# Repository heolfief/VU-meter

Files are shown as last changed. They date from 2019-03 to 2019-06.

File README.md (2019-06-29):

# VU-meter

<p align="center">
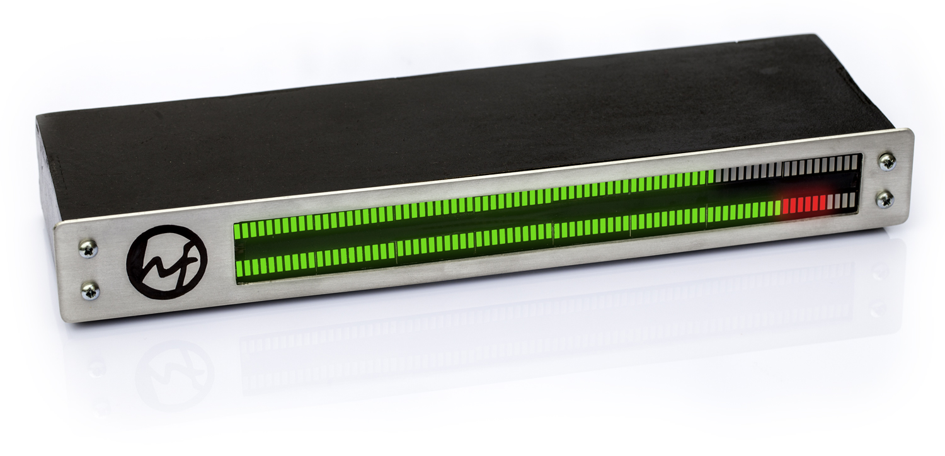
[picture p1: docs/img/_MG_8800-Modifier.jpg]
		
</p>

## Table of contents

- [Description](#description)
- [Hardware](#hardware)
- [Software](#software)
- [Copyright and license](#copyright-and-license)

## Description
This project is an AVR based LED VU-meter. It's display consists of 80 LEDs per audio channel. Each PCB holds all the LEDs, the analog and digital segments of the circuit and only handle one audio channel. That way you can build a stereo VU-meter just by using two instances of this circuit (which can be mechanically stacked together). Each audio channel will be completely separated and computed separately by the AVR microcontroller on each PCB.

### Pictures
<p align="center">
		
</p>
<p align="center">
		
</p>
<p align="center">
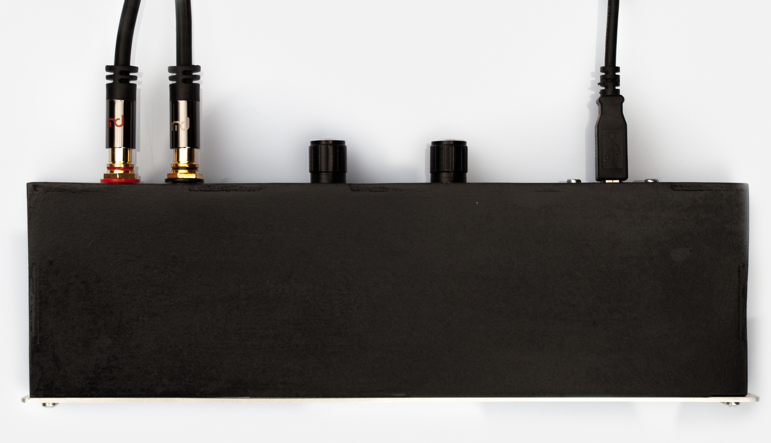
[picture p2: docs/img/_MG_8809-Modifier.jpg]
		
</p>

## Hardware
The hardware is based on 3 main components:
- ATmega328p AVR microcontroller
- MCP6004 quad op-amp
- 74HC595 shift-registers for extended MCU outputs

This board runs on 5V DC power and should not exceed 500mA of current draw (All LEDs lit up).
A stabilized power supply is needed in order to provide clean power to the analog circuit.

### PCB
Populated PCB picture:
<p align="center">
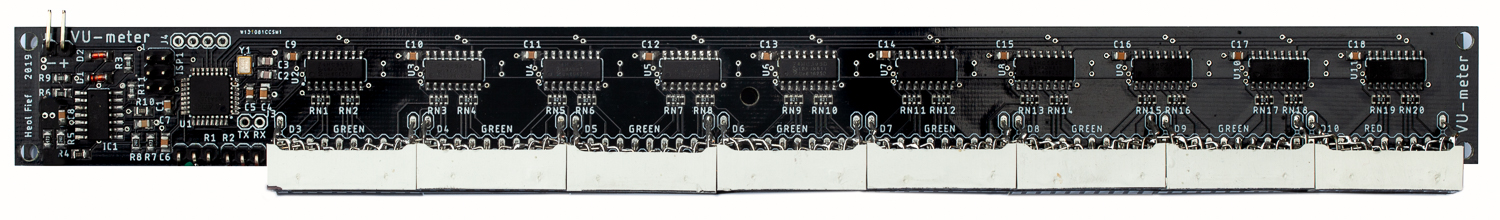
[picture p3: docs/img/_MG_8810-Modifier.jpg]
		
</p>

Bare PCB pictures:
<p align="center">
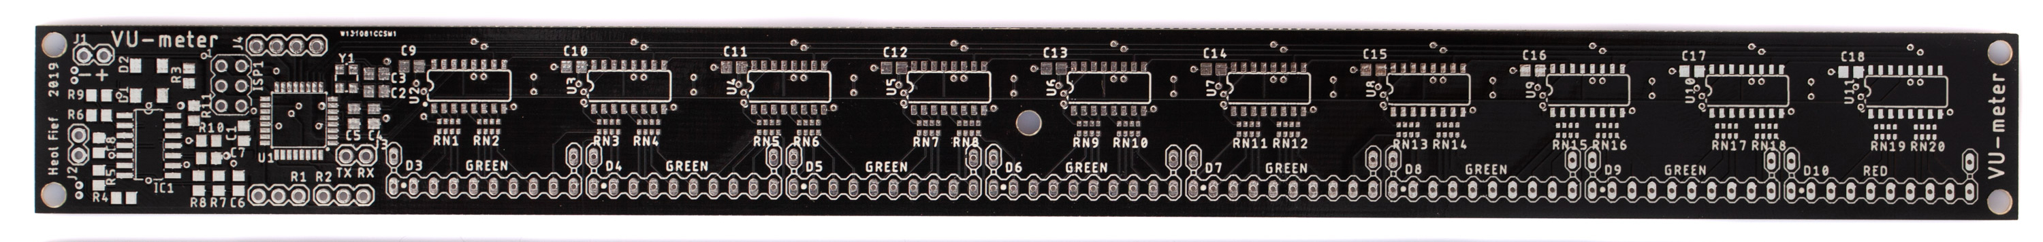
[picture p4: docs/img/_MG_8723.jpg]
		
</p>
<p align="center">
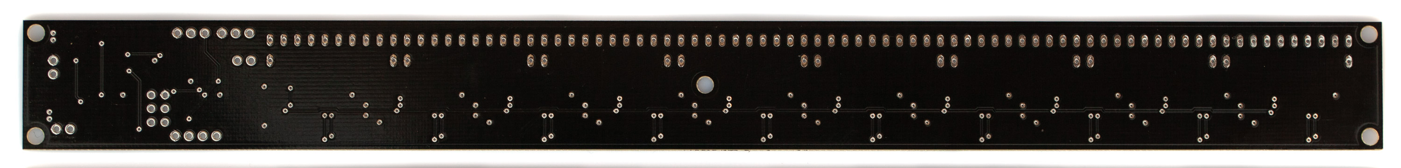
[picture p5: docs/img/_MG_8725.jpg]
		
</p>

The PCB was manufactured by <a target="_blank" href="https://www.pcbway.com">PCBWay</a>. Total cost was 44$ including shipping to France by DHL for 5 pieces.

I received the PCB 6 days after placing order on their website. General quality is good. Highly recommend their service.

<p align="center">
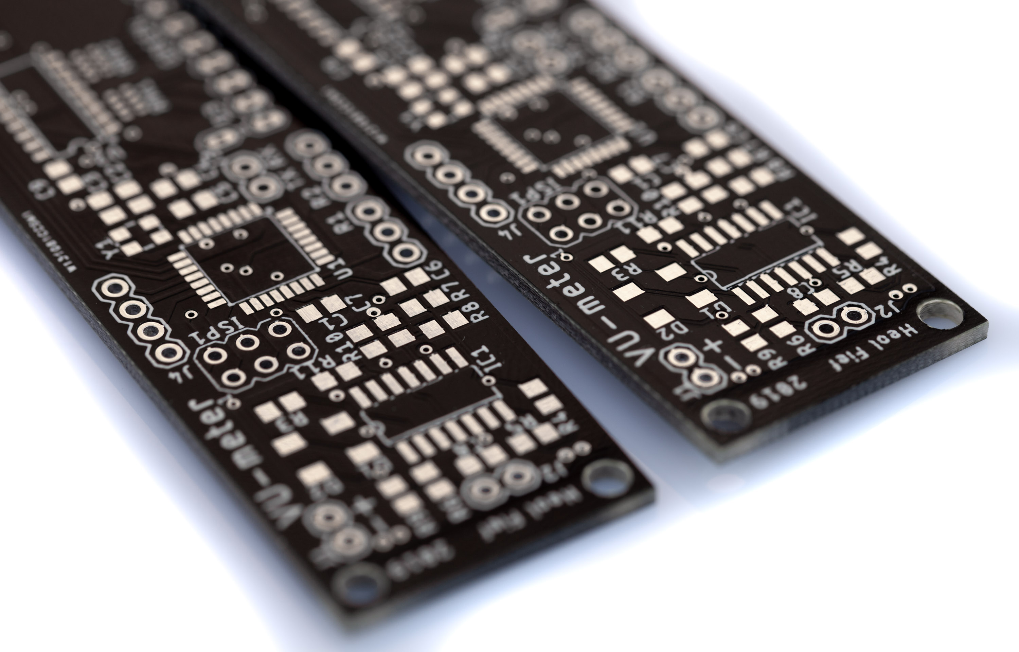
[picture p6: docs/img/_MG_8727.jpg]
		
</p>

### Documents available

- <a target="_blank" href="https://github.com/heolfief/VU-meter/blob/master/Hardware/Schematics.pdf">Schematics (PDF)</a>
- <a target="_blank" href="https://github.com/heolfief/VU-meter/blob/master/Hardware/BOM.pdf">Bill of materials (PDF)</a>
- <a target="_blank" href="https://github.com/heolfief/VU-meter/blob/master/Hardware/CAD/Eagle%20files">Autodesk Eagle CAD files</a>
- <a href="https://github.com/heolfief/VU-meter/tree/master/Hardware/CAD/GerberFiles">Gerber files</a>

## Software
The Firmware for the AVR microcontroller is written in C.

- IDE : Atmel Studio 7.0 (can be opened in MPLAB X)
- Compiler : avr-gcc

### Documents available

- <a target="_blank" href="https://heolfief.github.io/VU-meter/">Code documentation (doxygen)</a>

## Copyright and license
heolfief/VU-meter is licensed under the GNU General Public License v3.0.

See the <a target="_blank" href="https://github.com/heolfief/VU-meter/blob/master/LICENSE">LICENSE file</a> for more information.

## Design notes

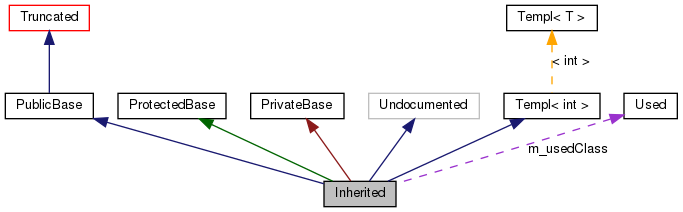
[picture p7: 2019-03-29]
docs/graph_legend.png

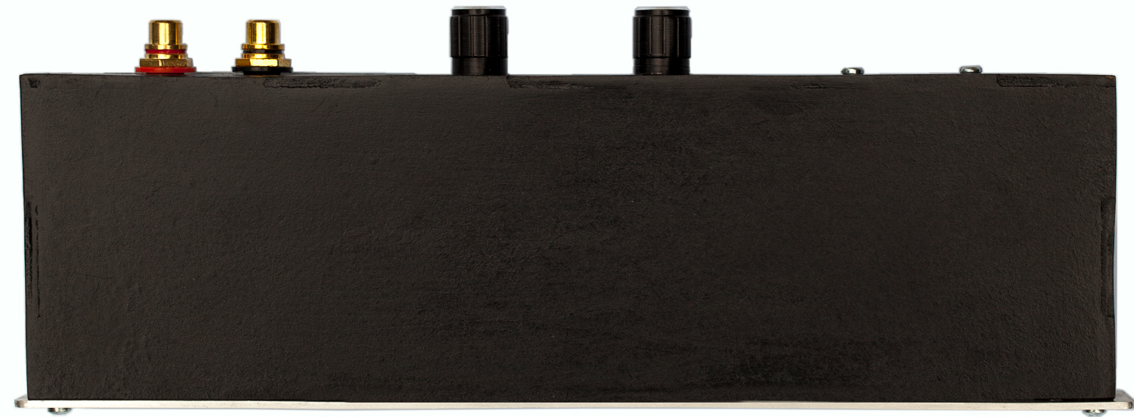
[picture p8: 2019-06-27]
docs/img/_MG_8802-Modifier.jpg

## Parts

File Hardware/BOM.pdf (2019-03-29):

BOM
Qty Value | Device | Package | Parts | Description
7 | 100k | R-EU_R0805 | R0805 | R3, R4, R5, R6, R9, R10, R11 | RESISTOR, European symbol
15 | 100n | C-EUC0805 | C0805 | C1, C4, C5, C6, C8, C9, C10, C11, C12, C13, C14, C15, C16, C17, C18 | CAPACITOR, European symbol
2 | 10k | POT_OFFBOARD | 1X03 | R1, R2 | Potentiometer with 3 pins connector for offboard wiring
1 | 16MHz | CRYSTALSMD-3.2X2.5 | CRYSTAL-SMD-3.2X2.5MM | Y1 | Crystals (Generic)
2 | 1N4148 | D-SOD-80 | SOD80 | D1, D2 | DIODE
1 | 22n | C-EUC0805 | C0805 | C7 | CAPACITOR, European symbol
2 | 22p | C-EUC0805 | C0805 | C2, C3 | CAPACITOR, European symbol
1 | 24k | R-EU_R0805 | R0805 | R8 | RESISTOR, European symbol
1 | 47k | R-EU_R0805 | R0805 | R7 | RESISTOR, European symbol
20 | 820 | 4R-N0603-ARC | 0603-ARC | | Array Chip Resistor
1 | ATMEGA328P_TQFP ATMEGA328P_TQFP | TQFP32-08 | U1 | Popular 328P in QFP
1 | AVRISP-6 | AVRISP-6 | AVRISP | ISP1 | AVR ISP HEADER
7 | GREEN | LED_BARGRAPH | LED_BARGRAPH | D3, D4, D5, D6, D7, D8, D9 | LED bargraph, right angle soldering
1 | MCP6004 | QUAD_OPAMPD | SO14 | IC1 | OP AMP
1 | PWR in (+5V) | CONN_02 | 1X02 | J1 | Generic Header 0.1 inch spaced
1 | SGNL_IN | CONN_02 | 1X02 | J2 | Generic Header 0.1 inch spaced
1 | RED | LED_BARGRAPH | LED_BARGRAPH | D10 | LED bargraph, right angle soldering
10 | SN74HC595D | 74HC595D | SO16 | U2, U3, U4, U5, U6, U7, U8, U9, U10, U11 | 8-Bit Shift Register (Serial to Parallel)

RN1, RN2, RN3, RN4, RN5, RN6, RN7, RN8, RN9, RN10, RN11, RN12, RN13, RN14, RN15, RN16, RN17, RN18, RN19, RN20

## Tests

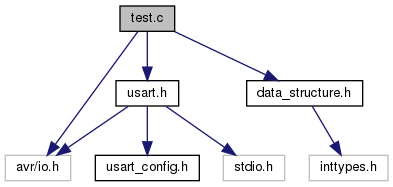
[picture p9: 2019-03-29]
docs/test_8c__incl.png

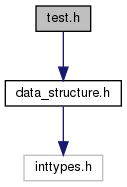
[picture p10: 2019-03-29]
docs/test_8h__incl.png

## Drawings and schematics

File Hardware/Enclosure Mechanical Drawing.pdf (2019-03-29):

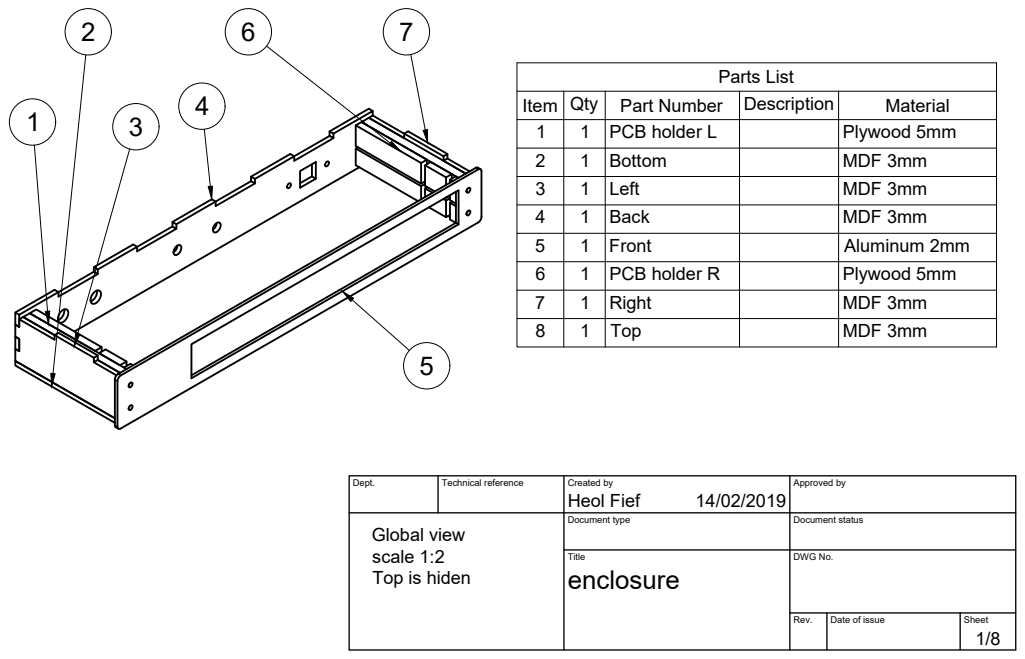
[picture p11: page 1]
Parts List

Item | Qty | Part Number | Description | Material
1 | 1 | PCB holder L | | Plywood 5mm
2 | 1 | Bottom | | MDF 3mm
3 | 1 | Left | | MDF 3mm
4 | 1 | Back | | MDF 3mm
5 | 1 | Front | | Aluminum 2mm
6 | 1 | PCB holder R | | Plywood 5mm
7 | 1 | Right | | MDF 3mm
8 | 1 | Top | | MDF 3mm

Dept. | Technical reference | Created by Heol Fief 14/02/2019 | Approved by

Global view scale 1:2 Top is hiden | | Document type | Document status

Title enclosure | DWG No.

Rev. | Date of issue | Sheet

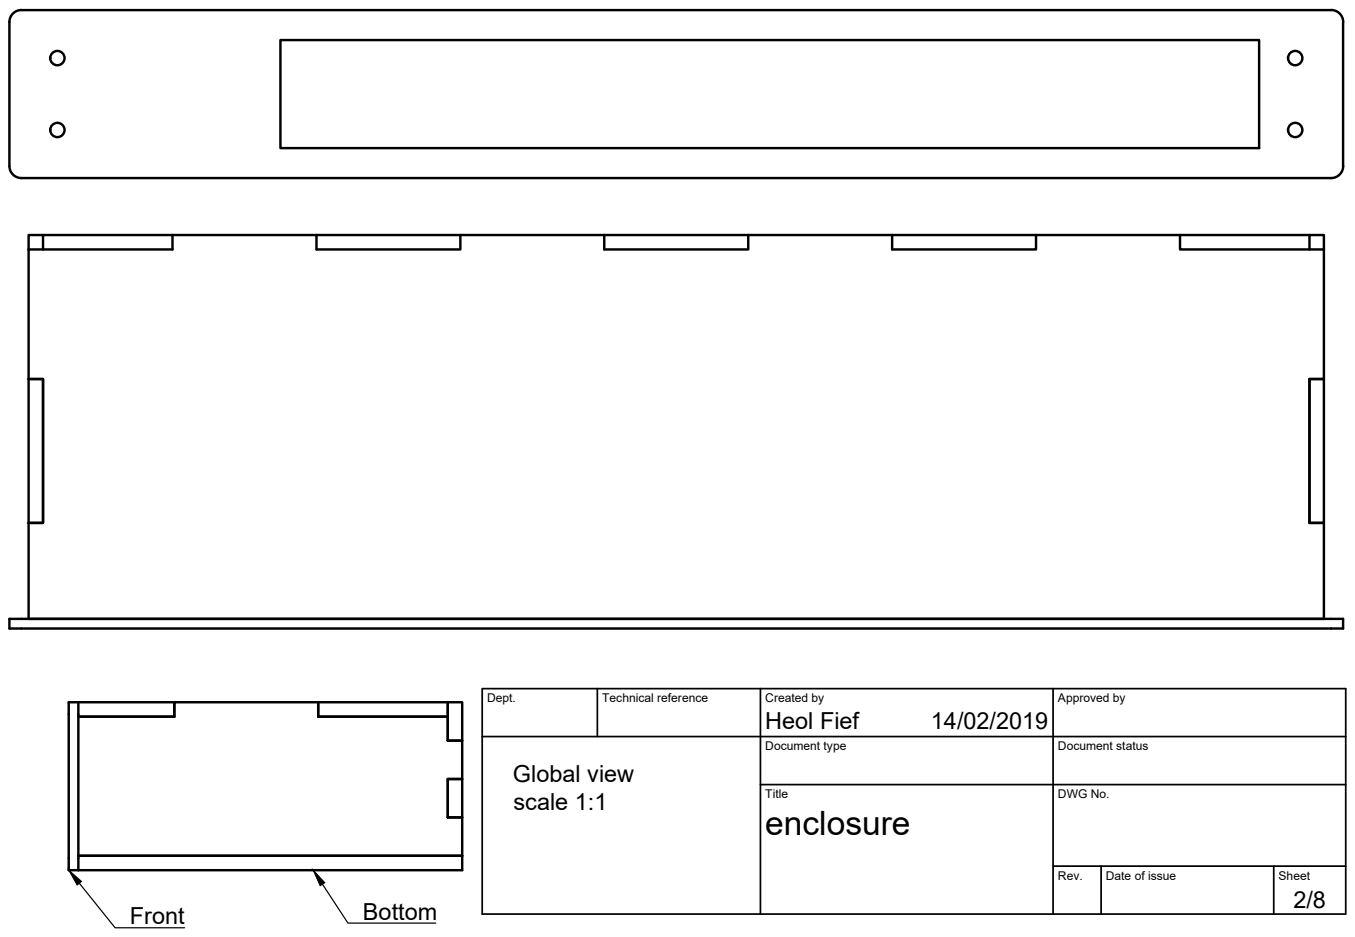
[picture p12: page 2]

Dept. | Technical reference | Created by Heol Fief 14/02/2019 | Approved by

Global view scale 1:1 | | Document type | Document status

Title enclosure | DWG No.

Rev. | Date of issue | Sheet

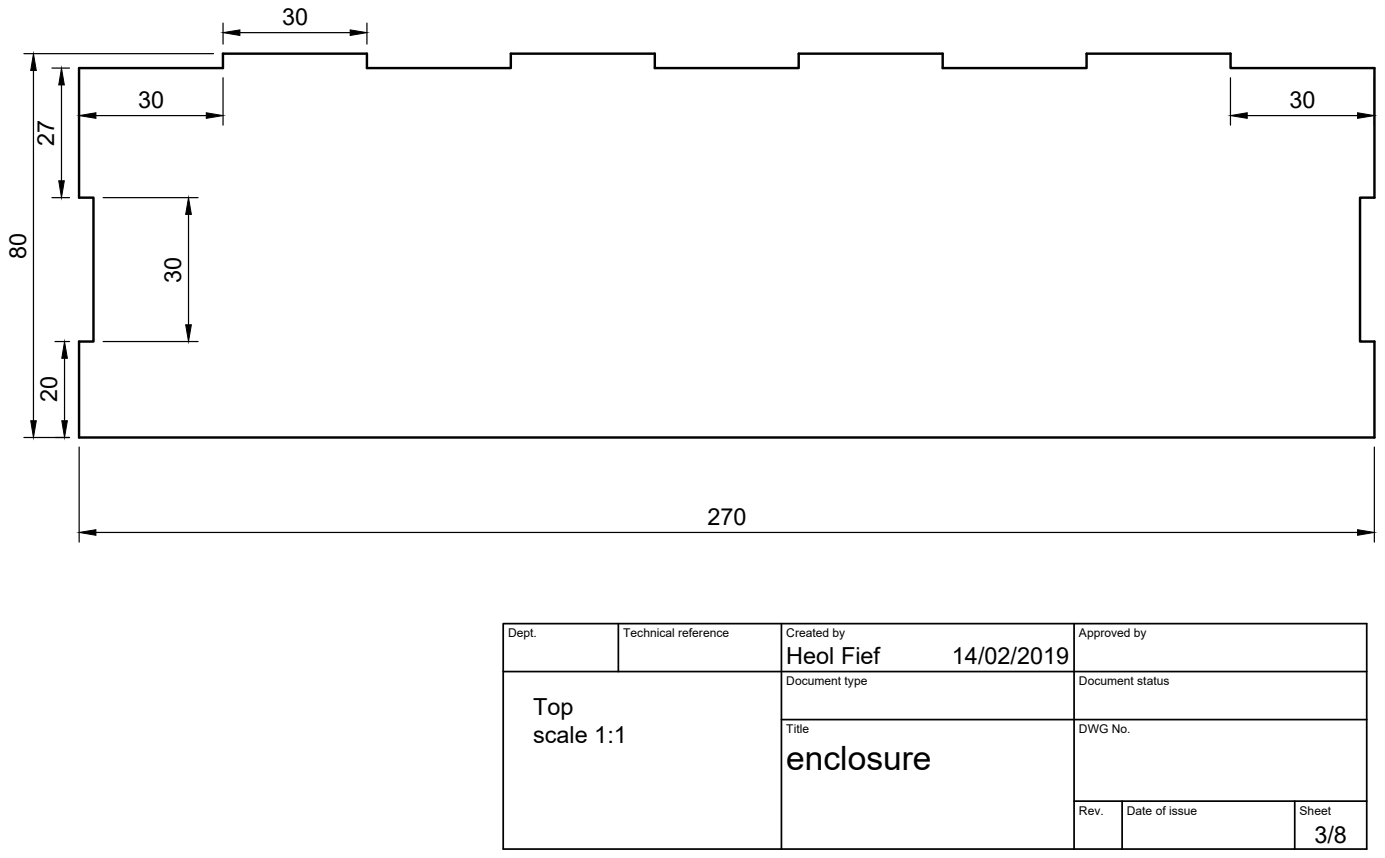
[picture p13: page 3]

Dept. | Technical reference | Created by Heol Fief 14/02/2019 | Approved by

Top scale 1:1 | | Document type | Document status

Title enclosure | DWG No.

Rev. | Date of issue | Sheet

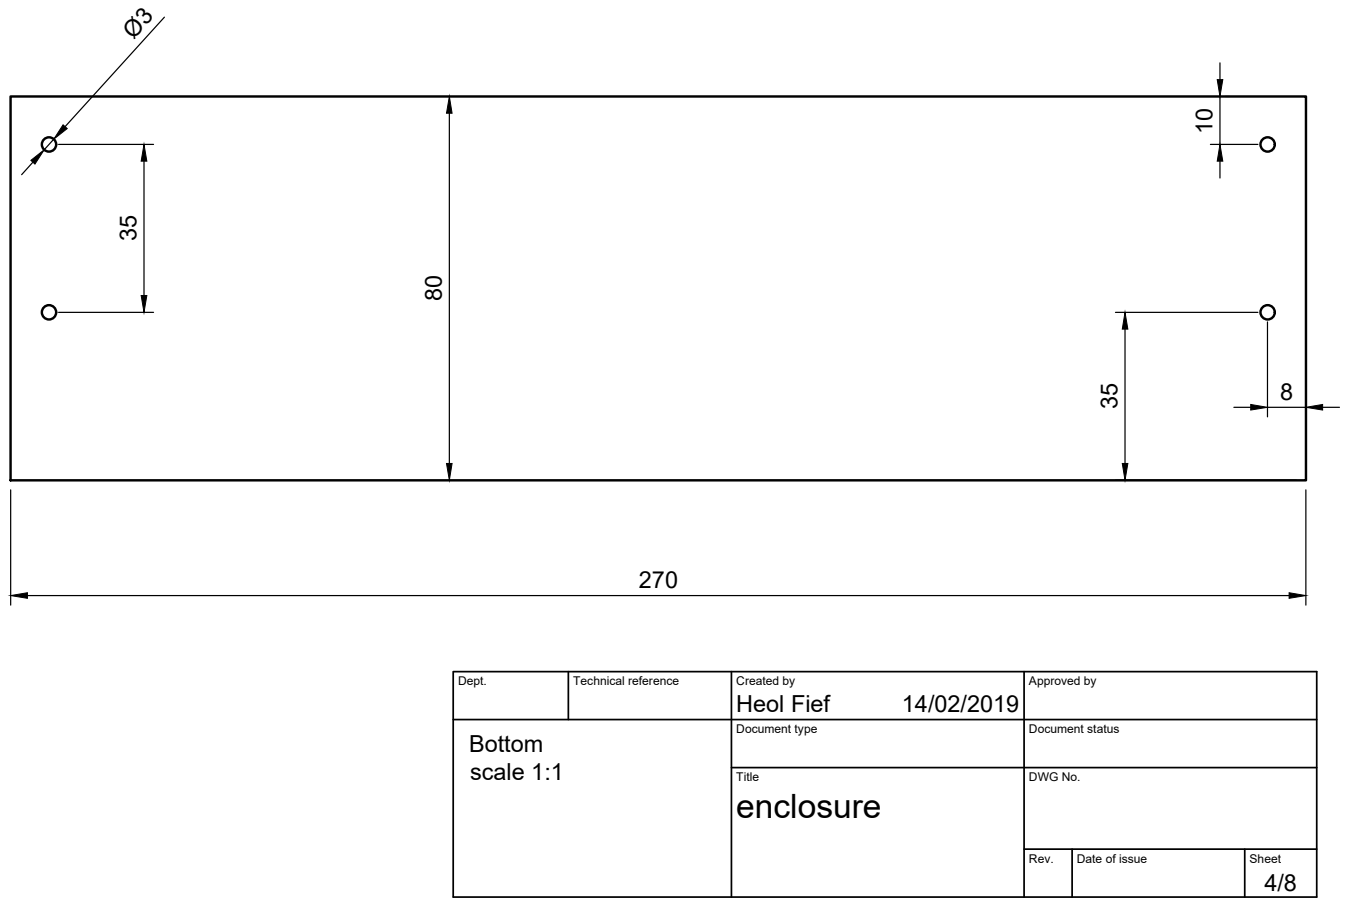
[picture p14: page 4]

Dept. | Technical reference | Created by Heol Fief 14/02/2019 | Approved by

Bottom scale 1:1 | | Document type | Document status

Title enclosure | DWG No.

Rev. | Date of issue | Sheet

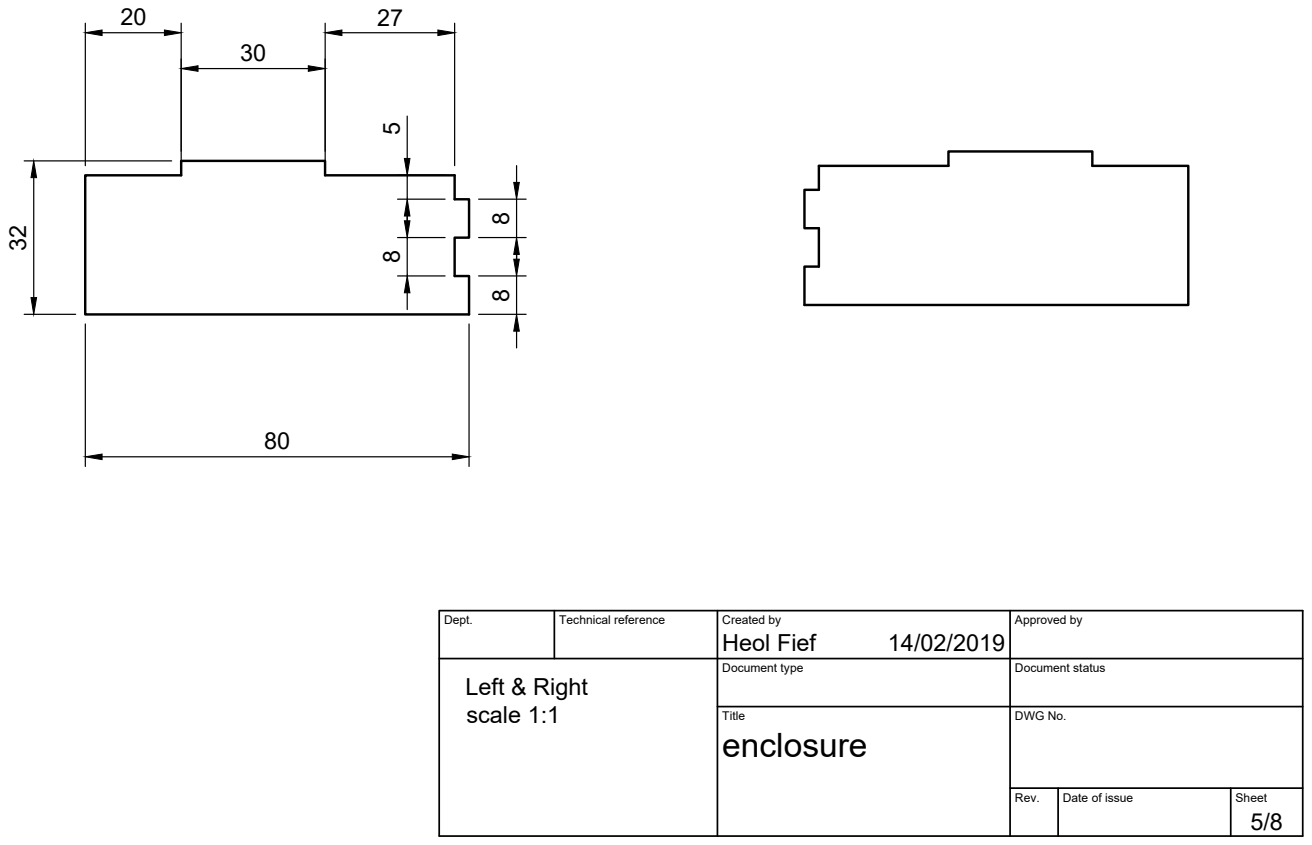
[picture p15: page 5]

Dept. | Technical reference | Created by Heol Fief 14/02/2019 | Approved by

Left & Right scale 1:1 | | Document type | Document status

Title enclosure | DWG No.

Rev. | Date of issue | Sheet

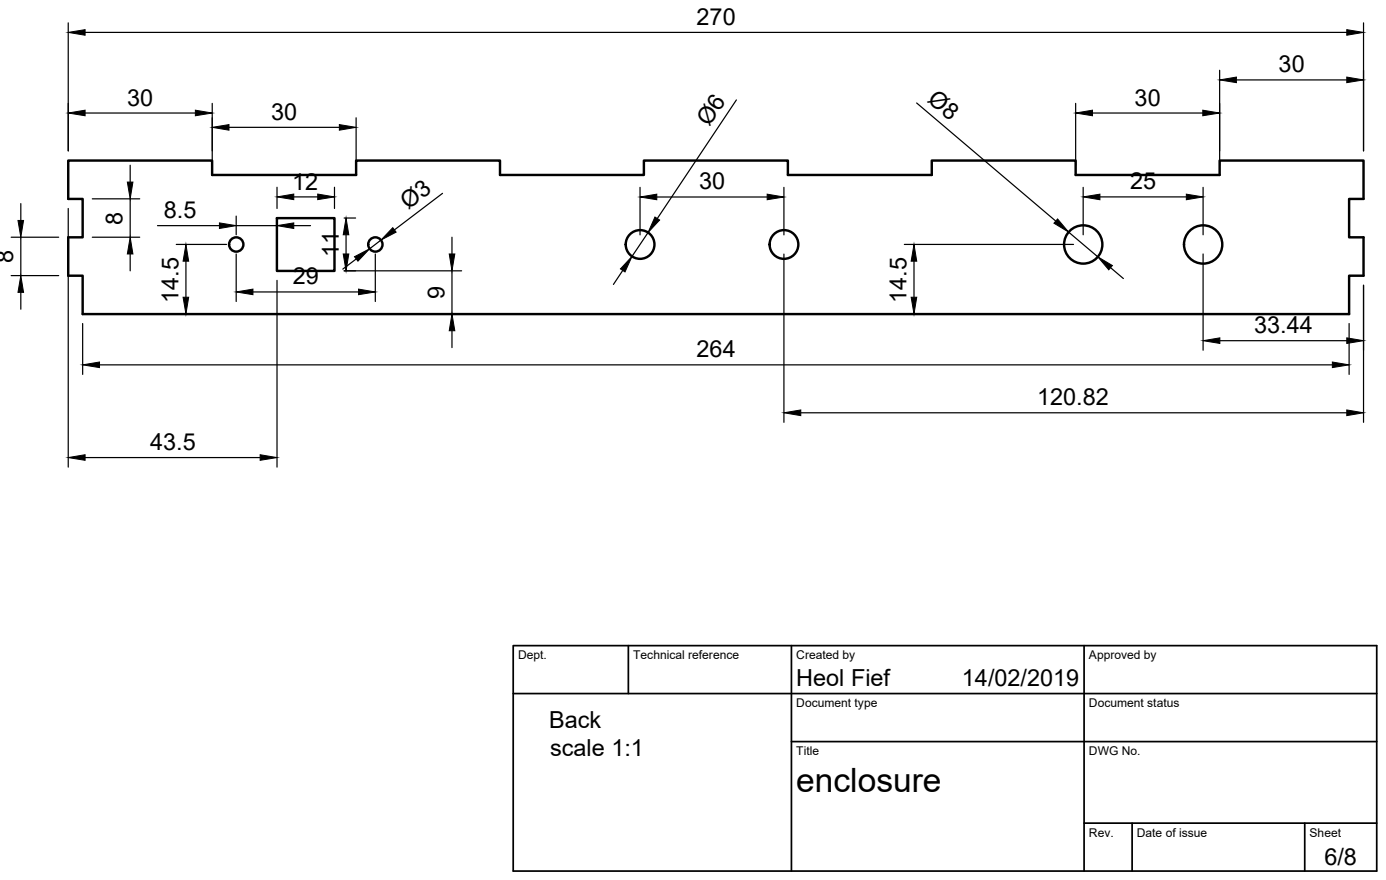
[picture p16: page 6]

Dept. | Technical reference | Created by Heol Fief 14/02/2019 | Approved by

Back scale 1:1 | | Document type | Document status

Title enclosure | DWG No.

Rev. | Date of issue | Sheet

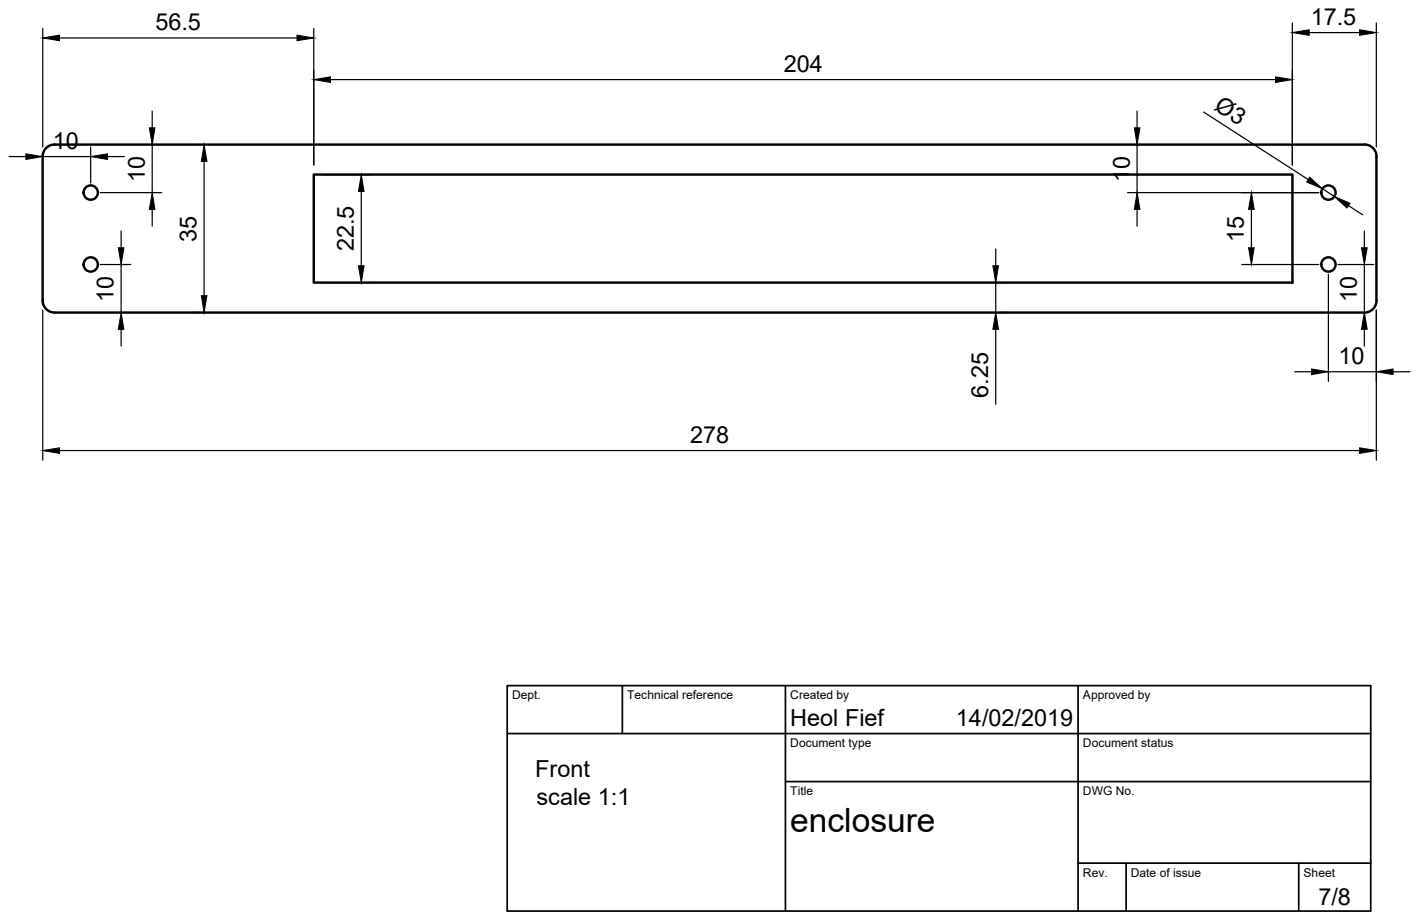
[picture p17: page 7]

Dept. | Technical reference | Created by Heol Fief 14/02/2019 | Approved by

Front scale 1:1 | | Document type | Document status

Title enclosure | DWG No.

Rev. | Date of issue | Sheet

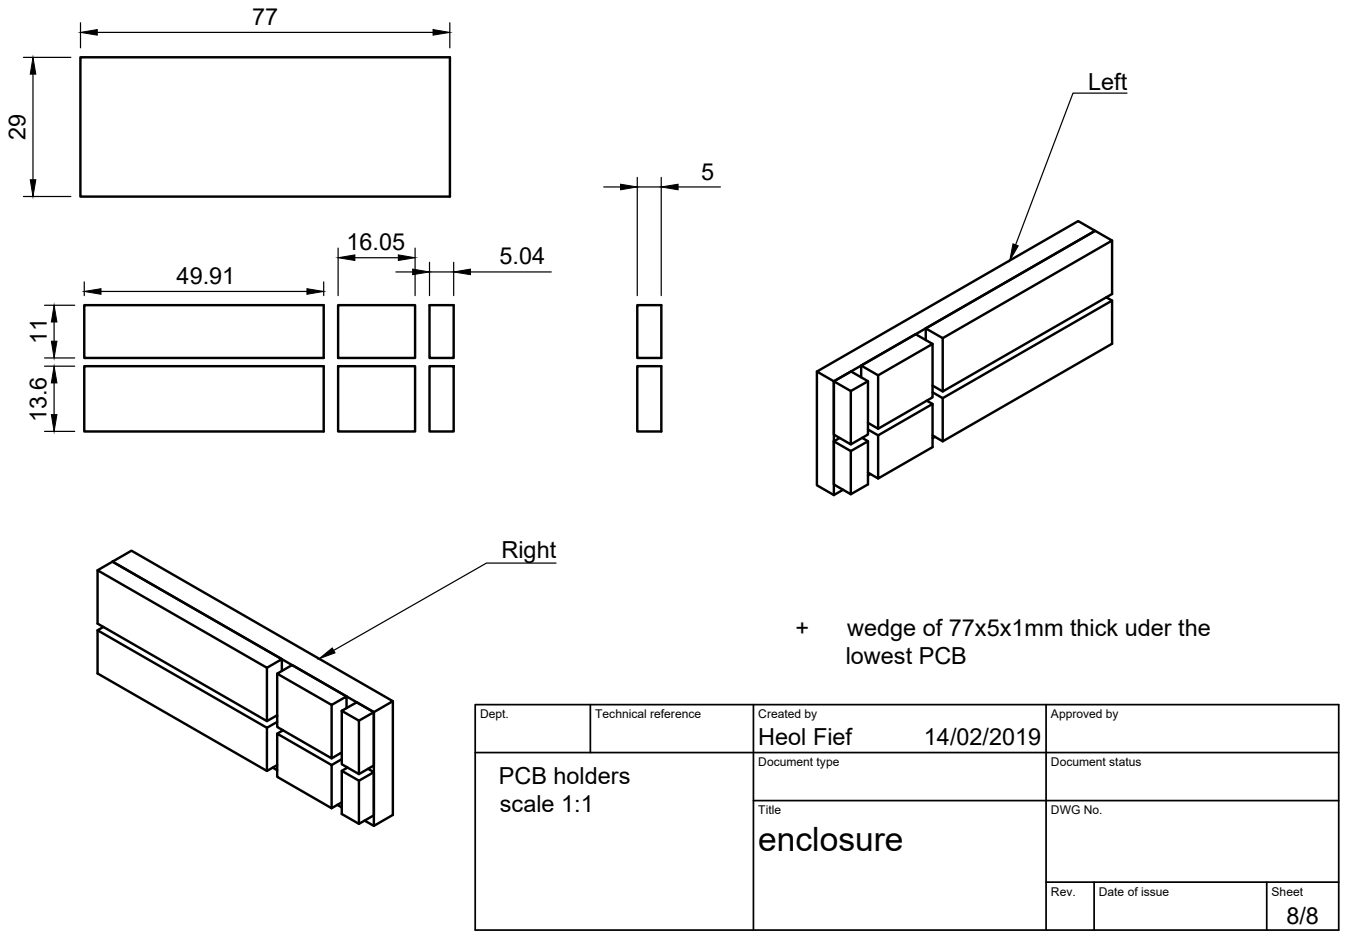
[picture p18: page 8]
Heol Fief 29; wedge of 77x5x1mm thick uder the; lowest PCB

Dept. | Technical reference | Created by 14/02/2019 | Approved by

PCB holders scale 1:1 | | Document type | Document status

Title enclosure | DWG No.

Rev. | Date of issue | Sheet

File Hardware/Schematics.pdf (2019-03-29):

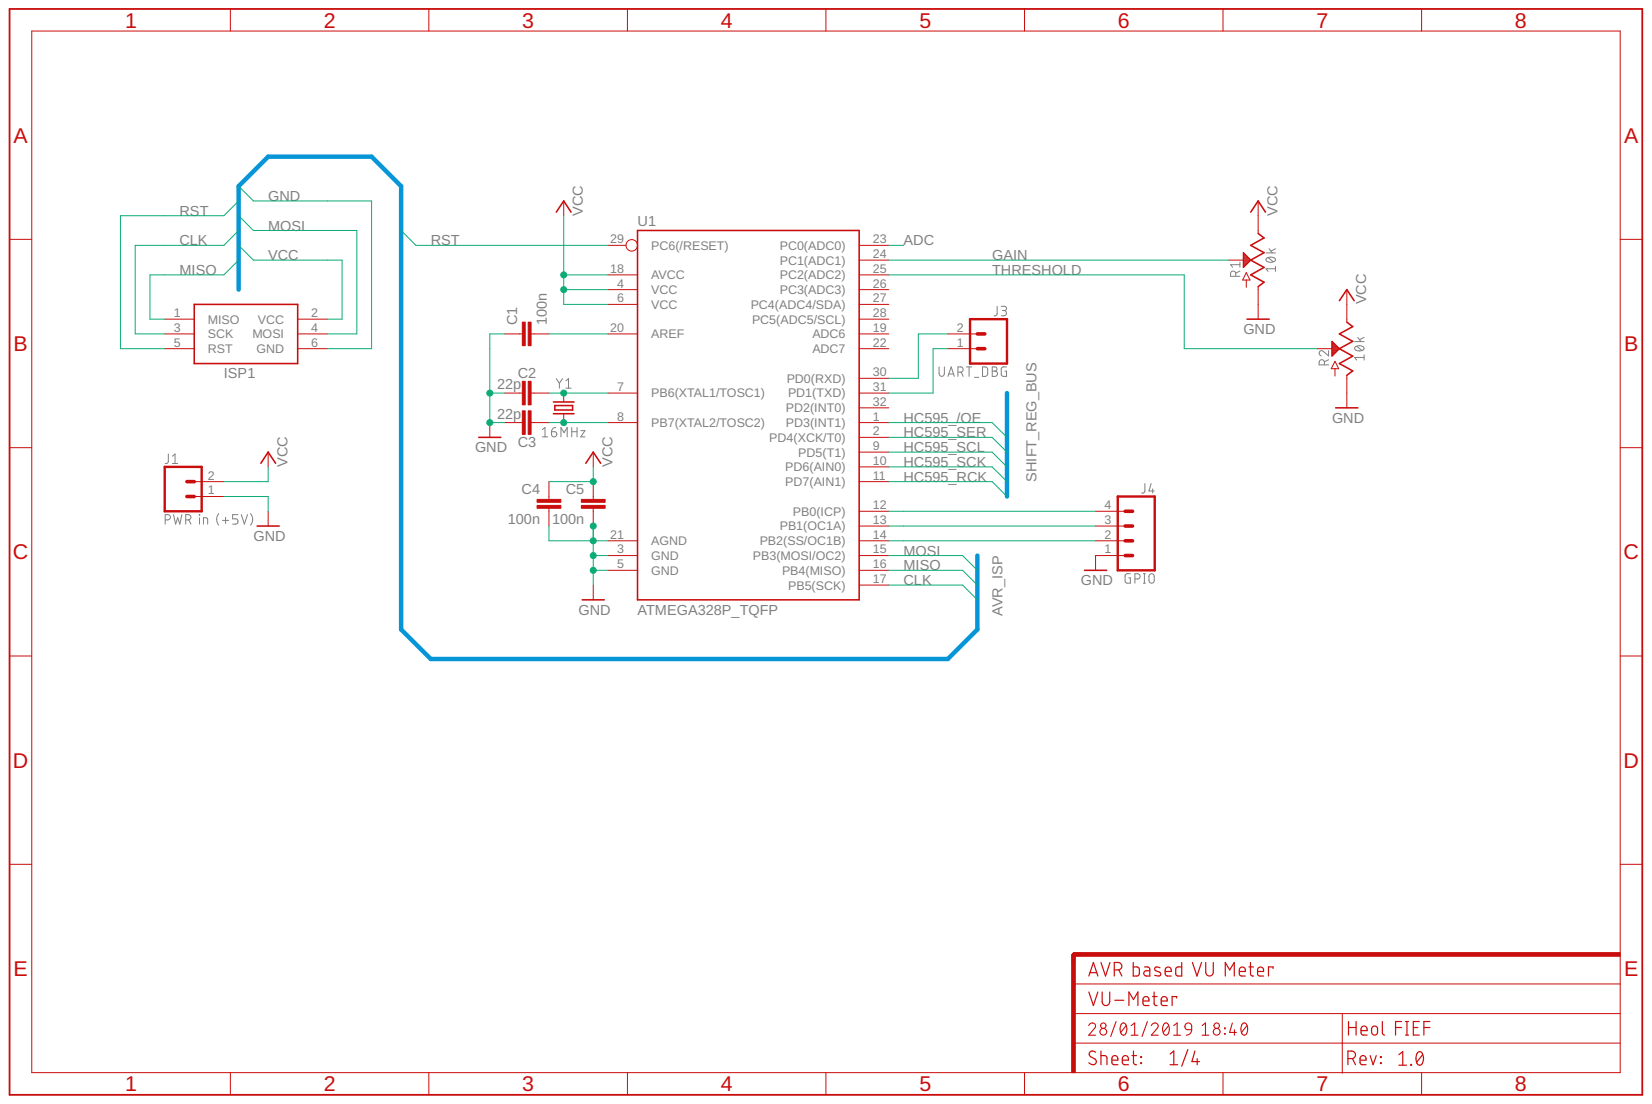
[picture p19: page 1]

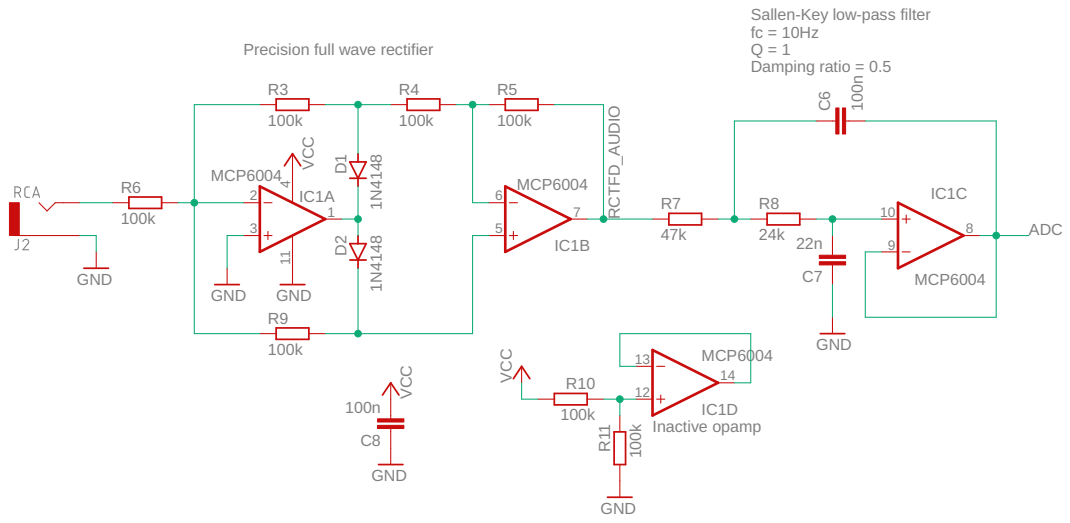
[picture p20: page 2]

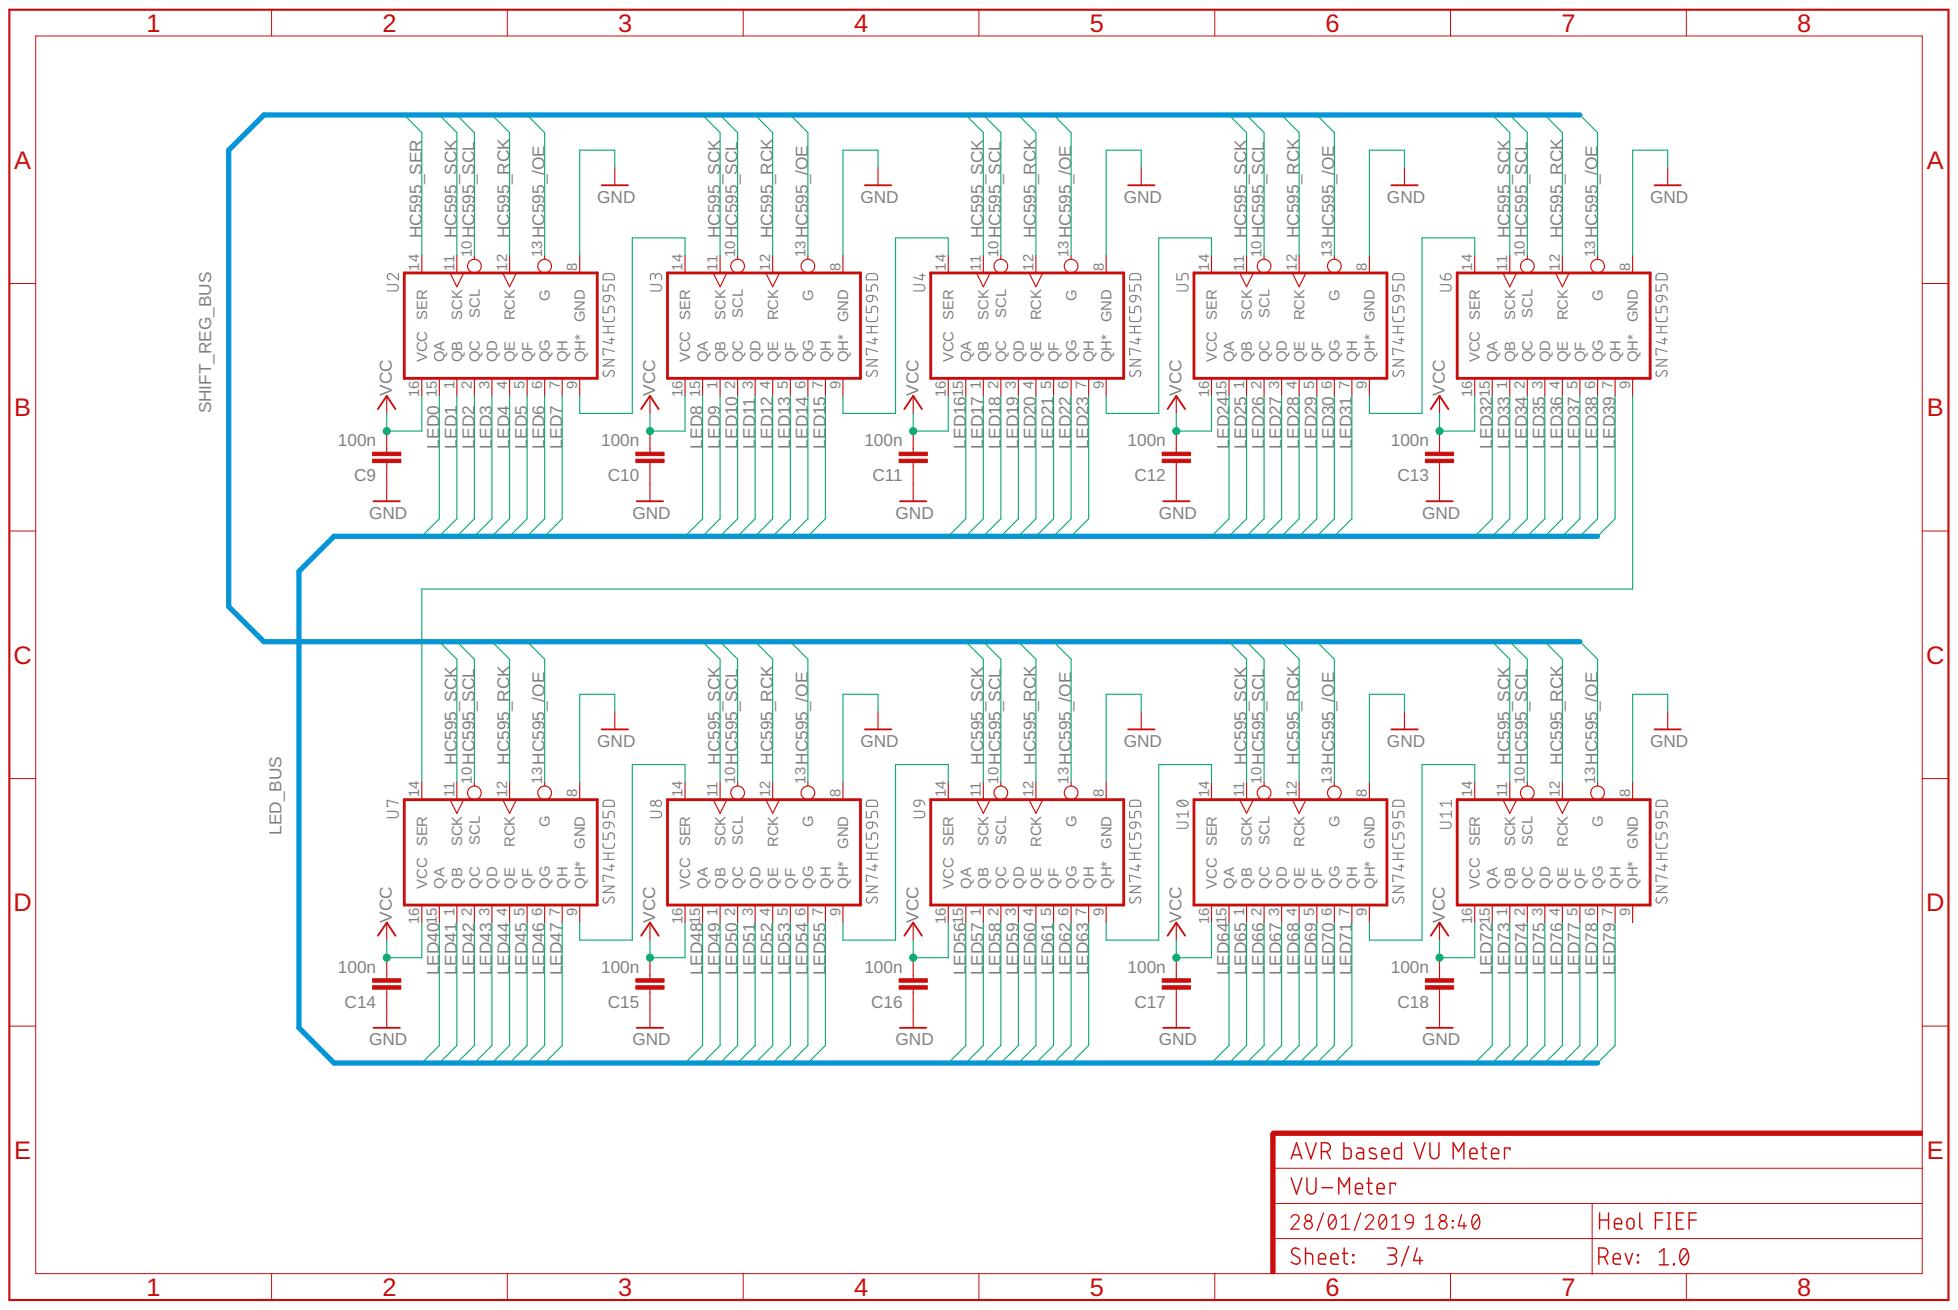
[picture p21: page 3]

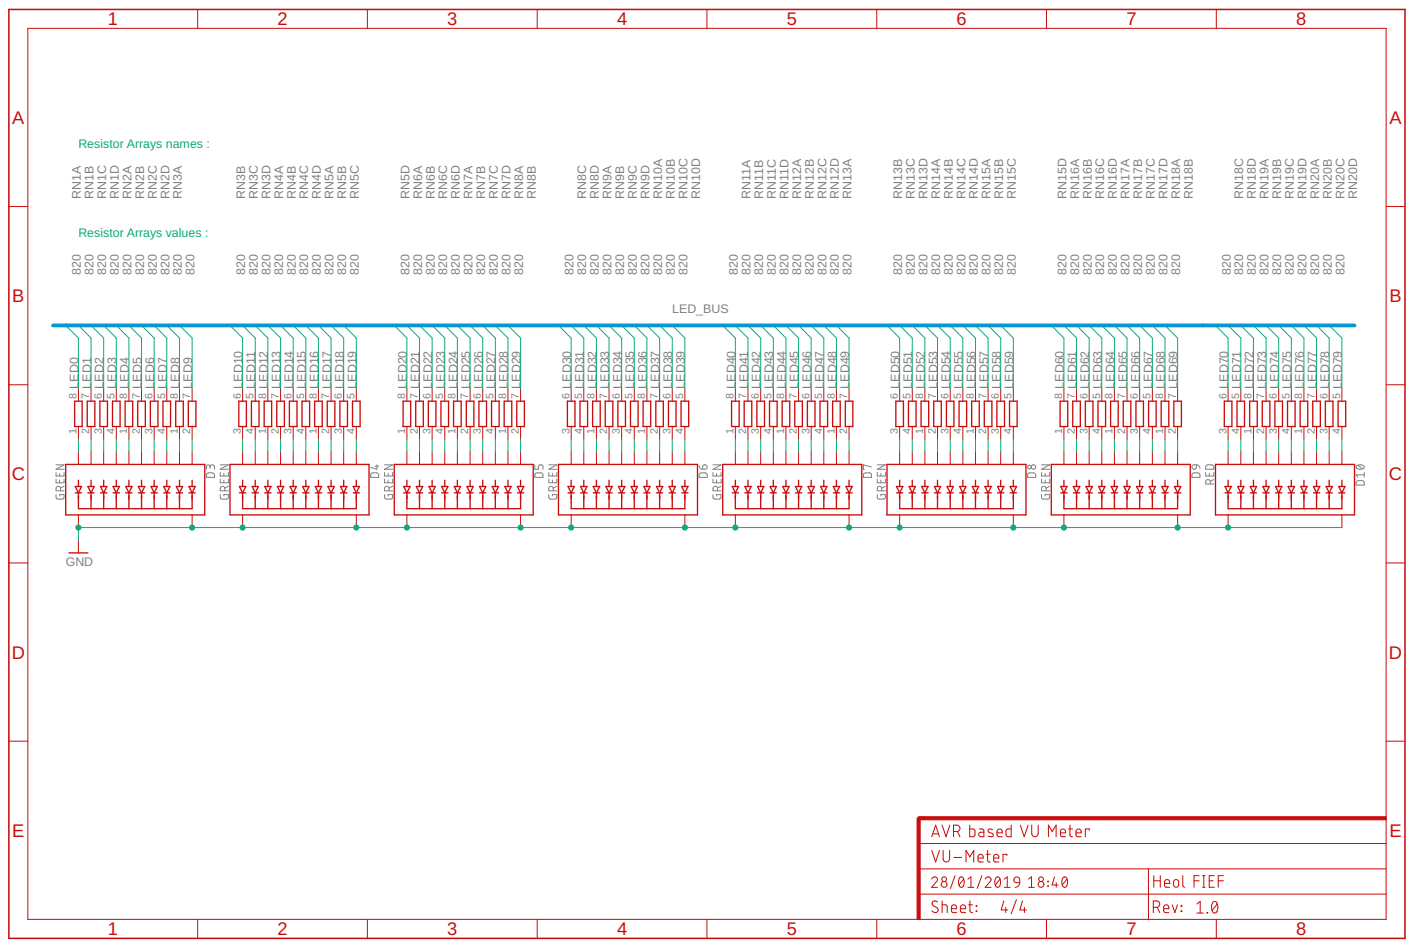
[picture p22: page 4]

Resistor Arrays names : Resistor Arrays values :

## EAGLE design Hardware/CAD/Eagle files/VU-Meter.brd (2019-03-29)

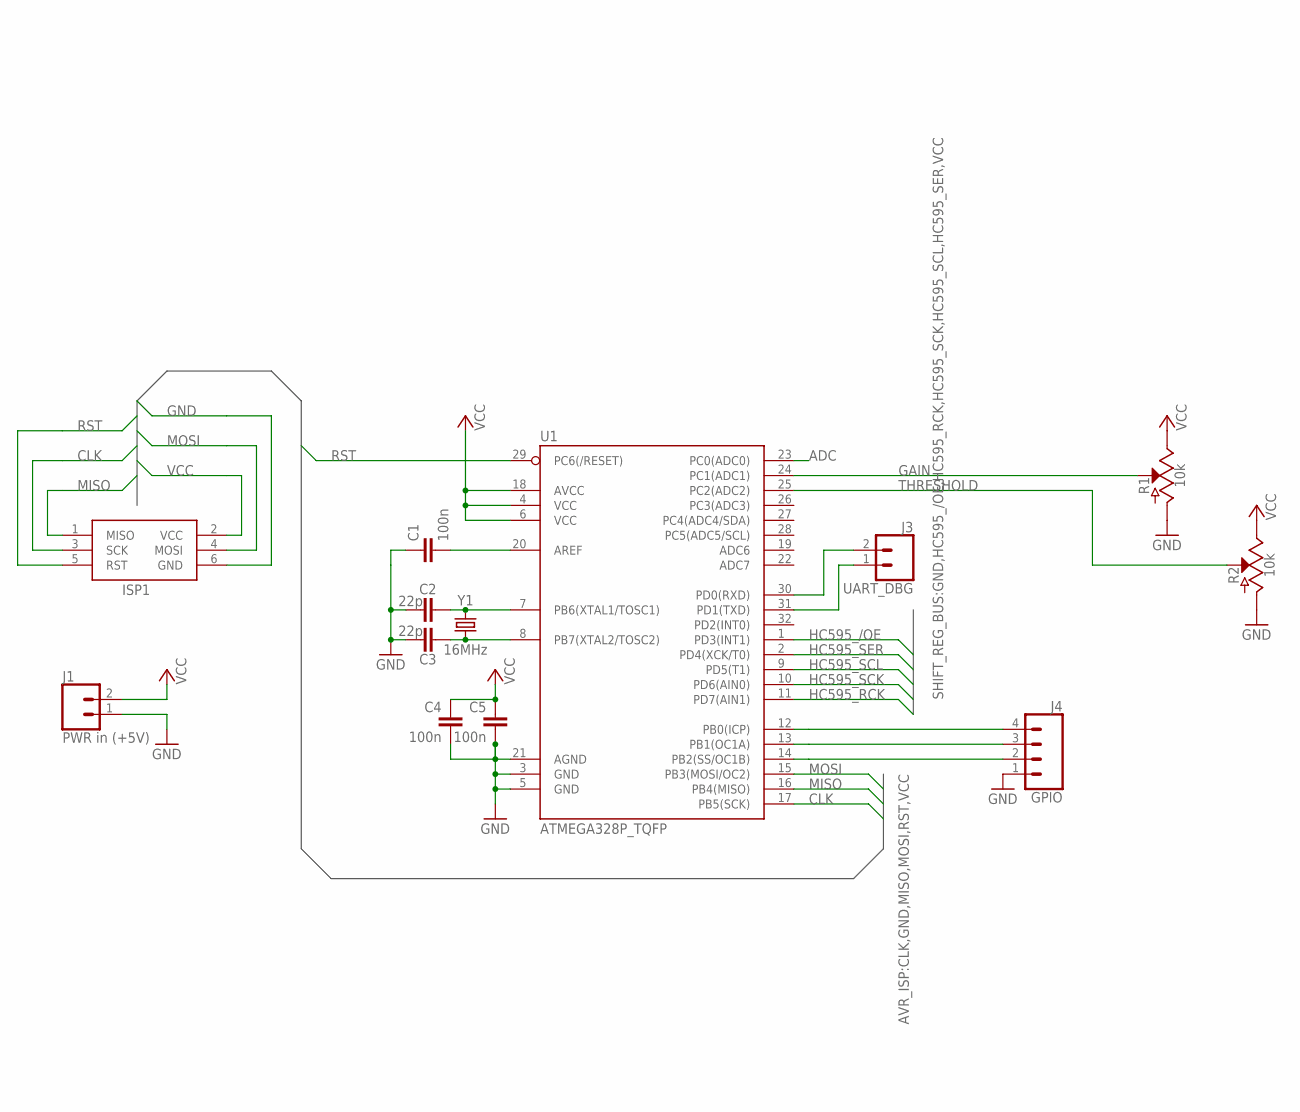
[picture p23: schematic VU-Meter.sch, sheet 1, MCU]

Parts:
C1, C4, C5: 100n; C0805
C2, C3: 22p; C0805
ISP1: AVRISP-6; AVRISP
J1: PWR in (+5V); 1X02
J3: UART_DBG; 1X02
J4: GPIO; 1X04
R1, R2: 10k; 1X03
U1: ATMEGA328P_TQFP; TQFP32-08
Y1: 16MHz; CRYSTAL-SMD-3.2X2.5MM

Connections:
ADC: U1.23 (PC0(ADC0)); also elsewhere on the board
CLK: ISP1.3 (SCK), U1.17 (PB5(SCK))
GAIN: R1.2 (S), U1.24 (PC1(ADC1))
GND: C1.1, C2.1, C3.1, C4.2, C5.2, ISP1.6 (GND), J1.1, J4.1, R1.3 (A), R2.3 (A), U1.3 (GND), U1.5 (GND), U1.21 (AGND); also elsewhere on the board
HC595_/OE: U1.1 (PD3(INT1)); also elsewhere on the board
HC595_RCK: U1.11 (PD7(AIN1)); also elsewhere on the board
HC595_SCK: U1.10 (PD6(AIN0)); also elsewhere on the board
HC595_SCL: U1.9 (PD5(T1)); also elsewhere on the board
HC595_SER: U1.2 (PD4(XCK/T0)); also elsewhere on the board
MISO: ISP1.1 (MISO), U1.16 (PB4(MISO))
MOSI: ISP1.4 (MOSI), U1.15 (PB3(MOSI/OC2))
unnamed: C1.2, U1.20 (AREF)
unnamed: C2.2, U1.7 (PB6(XTAL1/TOSC1)), Y1.3 (2)
unnamed: C3.2, U1.8 (PB7(XTAL2/TOSC2)), Y1.1
unnamed: J3.2, U1.30 (PD0(RXD))
unnamed: J3.1, U1.31 (PD1(TXD))
unnamed: J4.4, U1.12 (PB0(ICP))
unnamed: J4.3, U1.13 (PB1(OC1A))
unnamed: J4.2, U1.14 (PB2(SS/OC1B))
RST: ISP1.5 (RST), U1.29 (PC6(/RESET))
THRESHOLD: R2.2 (S), U1.25 (PC2(ADC2))
VCC: C4.1, C5.1, ISP1.2 (VCC), J1.2, R1.1 (E), R2.1 (E), U1.4 (VCC), U1.6 (VCC), U1.18 (AVCC); also elsewhere on the board

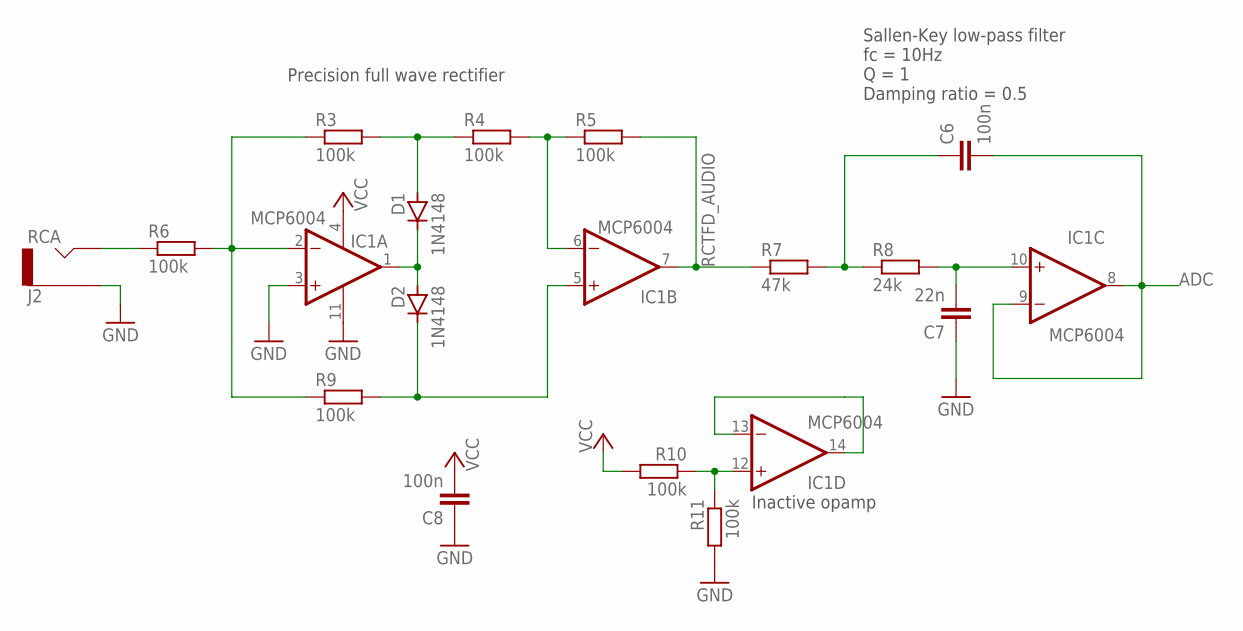
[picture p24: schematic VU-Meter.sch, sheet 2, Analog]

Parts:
C6, C8: 100n; C0805
C7: 22n; C0805
D1, D2: 1N4148; SOD80
IC1: MCP6004; SO14
J2: RCA; 1X02
R3, R4, R5, R6, R9, R10, R11: 100k; R0805
R7: 47k; R0805
R8: 24k; R0805

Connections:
ADC: C6.2, IC1.8 (OUT), IC1.9 (-IN); also elsewhere on the board
GND: C7.1, C8.1, IC1.3 (+IN), IC1.11 (V-), J2.2 (SLEEVE), R11.2; also elsewhere on the board
unnamed: IC1.2 (-IN), R3.1, R6.2, R9.1
unnamed: D2.1 (C), IC1.5 (+IN), R9.2
unnamed: D1.1 (C), D2.2 (A), IC1.1 (OUT)
unnamed: D1.2 (A), R3.2, R4.1
unnamed: IC1.6 (-IN), R4.2, R5.1
unnamed: J2.1 (TIP), R6.1
unnamed: C6.1, R7.2, R8.1
unnamed: C7.2, IC1.10 (+IN), R8.2
unnamed: IC1.13 (-IN), IC1.14 (OUT)
unnamed: IC1.12 (+IN), R10.1, R11.1
RCTFD_AUDIO: IC1.7 (OUT), R5.2, R7.1
VCC: C8.2, IC1.4 (V+), R10.2; also elsewhere on the board

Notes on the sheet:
Precision full wave rectifier
Sallen-Key low-pass filter fc = 10Hz Q = 1 Damping ratio = 0.5
Inactive opamp

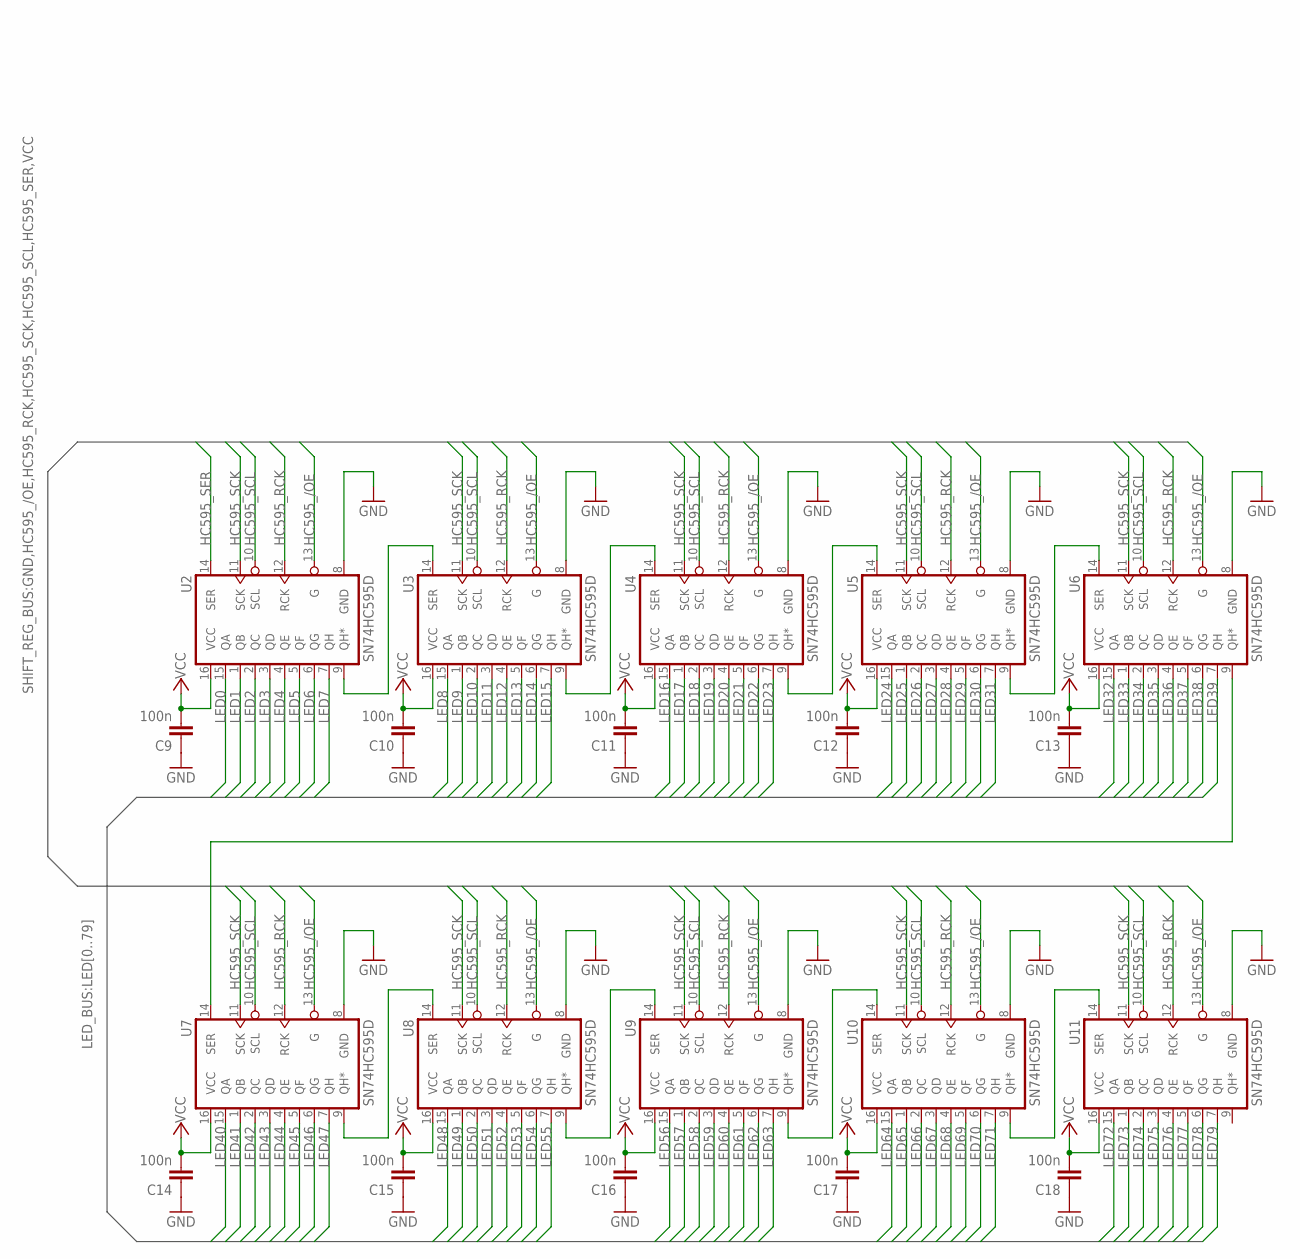
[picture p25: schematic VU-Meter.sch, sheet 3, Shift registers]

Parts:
C9, C10, C11, C12, C13, C14, C15, C16, C17, C18: 100n; C0805
U2, U3, U4, U5, U6, U7, U8, U9, U10, U11: SN74HC595D; SO16

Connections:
GND: C9.1, C10.1, C11.1, C12.1, C13.1, C14.1, C15.1, C16.1, C17.1, C18.1, U2.8 (GND), U3.8 (GND), U4.8 (GND), U5.8 (GND), U6.8 (GND), U7.8 (GND), U8.8 (GND), U9.8 (GND), U10.8 (GND), U11.8 (GND); also elsewhere on the board
HC595_/OE: U2.13 (G), U3.13 (G), U4.13 (G), U5.13 (G), U6.13 (G), U7.13 (G), U8.13 (G), U9.13 (G), U10.13 (G), U11.13 (G); also elsewhere on the board
HC595_RCK: U2.12 (RCK), U3.12 (RCK), U4.12 (RCK), U5.12 (RCK), U6.12 (RCK), U7.12 (RCK), U8.12 (RCK), U9.12 (RCK), U10.12 (RCK), U11.12 (RCK); also elsewhere on the board
HC595_SCK: U2.11 (SCK), U3.11 (SCK), U4.11 (SCK), U5.11 (SCK), U6.11 (SCK), U7.11 (SCK), U8.11 (SCK), U9.11 (SCK), U10.11 (SCK), U11.11 (SCK); also elsewhere on the board
HC595_SCL: U2.10 (SCL), U3.10 (SCL), U4.10 (SCL), U5.10 (SCL), U6.10 (SCL), U7.10 (SCL), U8.10 (SCL), U9.10 (SCL), U10.10 (SCL), U11.10 (SCL); also elsewhere on the board
HC595_SER: U2.14 (SER); also elsewhere on the board
LED0: U2.15 (QA); also elsewhere on the board
LED1: U2.1 (QB); also elsewhere on the board
LED2: U2.2 (QC); also elsewhere on the board
LED3: U2.3 (QD); also elsewhere on the board
LED4: U2.4 (QE); also elsewhere on the board
LED5: U2.5 (QF); also elsewhere on the board
LED6: U2.6 (QG); also elsewhere on the board
LED7: U2.7 (QH); also elsewhere on the board
LED8: U3.15 (QA); also elsewhere on the board
LED9: U3.1 (QB); also elsewhere on the board
LED10: U3.2 (QC); also elsewhere on the board
LED11: U3.3 (QD); also elsewhere on the board
LED12: U3.4 (QE); also elsewhere on the board
LED13: U3.5 (QF); also elsewhere on the board
LED14: U3.6 (QG); also elsewhere on the board
LED15: U3.7 (QH); also elsewhere on the board
LED16: U4.15 (QA); also elsewhere on the board
LED17: U4.1 (QB); also elsewhere on the board
LED18: U4.2 (QC); also elsewhere on the board
LED19: U4.3 (QD); also elsewhere on the board
LED20: U4.4 (QE); also elsewhere on the board
LED21: U4.5 (QF); also elsewhere on the board
LED22: U4.6 (QG); also elsewhere on the board
LED23: U4.7 (QH); also elsewhere on the board
LED24: U5.15 (QA); also elsewhere on the board
LED25: U5.1 (QB); also elsewhere on the board
LED26: U5.2 (QC); also elsewhere on the board
LED27: U5.3 (QD); also elsewhere on the board
LED28: U5.4 (QE); also elsewhere on the board
LED29: U5.5 (QF); also elsewhere on the board
LED30: U5.6 (QG); also elsewhere on the board
LED31: U5.7 (QH); also elsewhere on the board
LED32: U6.15 (QA); also elsewhere on the board
LED33: U6.1 (QB); also elsewhere on the board
LED34: U6.2 (QC); also elsewhere on the board
LED35: U6.3 (QD); also elsewhere on the board
LED36: U6.4 (QE); also elsewhere on the board
LED37: U6.5 (QF); also elsewhere on the board
LED38: U6.6 (QG); also elsewhere on the board
LED39: U6.7 (QH); also elsewhere on the board
LED40: U7.15 (QA); also elsewhere on the board
LED41: U7.1 (QB); also elsewhere on the board
LED42: U7.2 (QC); also elsewhere on the board
LED43: U7.3 (QD); also elsewhere on the board
LED44: U7.4 (QE); also elsewhere on the board
LED45: U7.5 (QF); also elsewhere on the board
LED46: U7.6 (QG); also elsewhere on the board
LED47: U7.7 (QH); also elsewhere on the board
LED48: U8.15 (QA); also elsewhere on the board
LED49: U8.1 (QB); also elsewhere on the board
LED50: U8.2 (QC); also elsewhere on the board
LED51: U8.3 (QD); also elsewhere on the board
LED52: U8.4 (QE); also elsewhere on the board
LED53: U8.5 (QF); also elsewhere on the board
LED54: U8.6 (QG); also elsewhere on the board
LED55: U8.7 (QH); also elsewhere on the board
LED56: U9.15 (QA); also elsewhere on the board
LED57: U9.1 (QB); also elsewhere on the board
LED58: U9.2 (QC); also elsewhere on the board
LED59: U9.3 (QD); also elsewhere on the board
LED60: U9.4 (QE); also elsewhere on the board
LED61: U9.5 (QF); also elsewhere on the board
LED62: U9.6 (QG); also elsewhere on the board
LED63: U9.7 (QH); also elsewhere on the board
LED64: U10.15 (QA); also elsewhere on the board
LED65: U10.1 (QB); also elsewhere on the board
LED66: U10.2 (QC); also elsewhere on the board
LED67: U10.3 (QD); also elsewhere on the board
LED68: U10.4 (QE); also elsewhere on the board
LED69: U10.5 (QF); also elsewhere on the board
LED70: U10.6 (QG); also elsewhere on the board
LED71: U10.7 (QH); also elsewhere on the board
LED72: U11.15 (QA); also elsewhere on the board
LED73: U11.1 (QB); also elsewhere on the board
LED74: U11.2 (QC); also elsewhere on the board
LED75: U11.3 (QD); also elsewhere on the board
LED76: U11.4 (QE); also elsewhere on the board
LED77: U11.5 (QF); also elsewhere on the board
LED78: U11.6 (QG); also elsewhere on the board
LED79: U11.7 (QH); also elsewhere on the board
unnamed: U2.9 (QH*), U3.14 (SER)
unnamed: U3.9 (QH*), U4.14 (SER)
unnamed: U4.9 (QH*), U5.14 (SER)
unnamed: U5.9 (QH*), U6.14 (SER)
unnamed: U7.9 (QH*), U8.14 (SER)
unnamed: U8.9 (QH*), U9.14 (SER)
unnamed: U9.9 (QH*), U10.14 (SER)
unnamed: U10.9 (QH*), U11.14 (SER)
unnamed: U6.9 (QH*), U7.14 (SER)
VCC: C9.2, C10.2, C11.2, C12.2, C13.2, C14.2, C15.2, C16.2, C17.2, C18.2, U2.16 (VCC), U3.16 (VCC), U4.16 (VCC), U5.16 (VCC), U6.16 (VCC), U7.16 (VCC), U8.16 (VCC), U9.16 (VCC), U10.16 (VCC), U11.16 (VCC); also elsewhere on the board

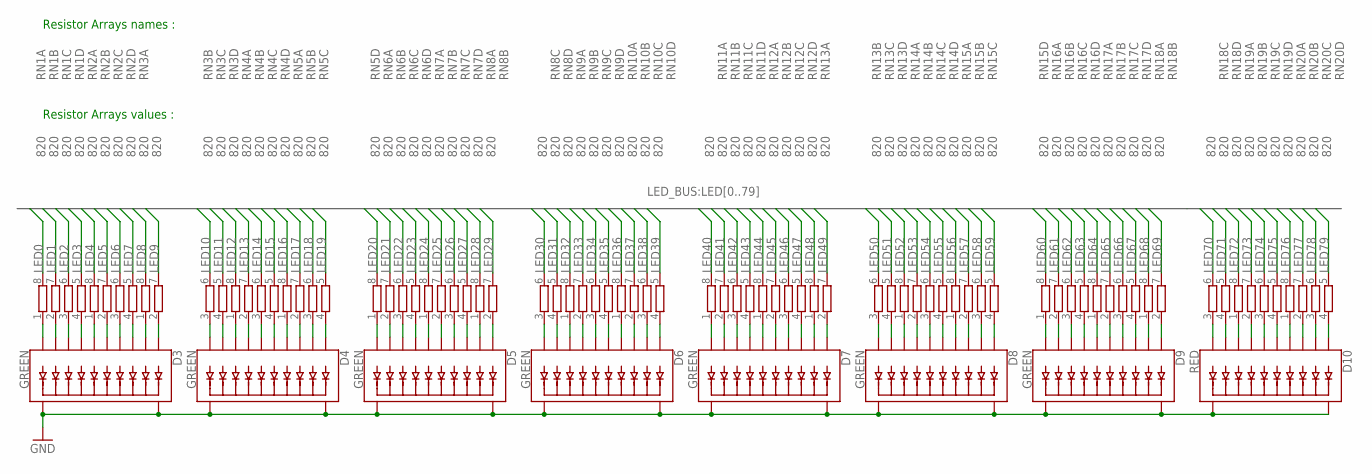
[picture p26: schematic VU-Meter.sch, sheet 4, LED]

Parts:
D3, D4, D5, D6, D7, D8, D9: GREEN; LED_BARGRAPH_OFFBOARD_RIGHT_ANGLE
D10: RED; LED_BARGRAPH_OFFBOARD_RIGHT_ANGLE
RN1, RN2, RN3, RN4, RN5, RN6, RN7, RN8, RN9, RN10, RN11, RN12, RN13, RN14, RN15, RN16, RN17, RN18, RN19, RN20: 820; 0603-ARC

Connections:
GND: D3.P$11 (C), D3.P$12 (C1), D4.P$11 (C), D4.P$12 (C1), D5.P$11 (C), D5.P$12 (C1), D6.P$11 (C), D6.P$12 (C1), D7.P$11 (C), D7.P$12 (C1), D8.P$11 (C), D8.P$12 (C1), D9.P$11 (C), D9.P$12 (C1), D10.P$11 (C), D10.P$12 (C1); also elsewhere on the board
LED0: RN1.8 (2); also elsewhere on the board
LED1: RN1.7 (2); also elsewhere on the board
LED2: RN1.6 (2); also elsewhere on the board
LED3: RN1.5 (2); also elsewhere on the board
LED4: RN2.8 (2); also elsewhere on the board
LED5: RN2.7 (2); also elsewhere on the board
LED6: RN2.6 (2); also elsewhere on the board
LED7: RN2.5 (2); also elsewhere on the board
LED8: RN3.8 (2); also elsewhere on the board
LED9: RN3.7 (2); also elsewhere on the board
LED10: RN3.6 (2); also elsewhere on the board
LED11: RN3.5 (2); also elsewhere on the board
LED12: RN4.8 (2); also elsewhere on the board
LED13: RN4.7 (2); also elsewhere on the board
LED14: RN4.6 (2); also elsewhere on the board
LED15: RN4.5 (2); also elsewhere on the board
LED16: RN5.8 (2); also elsewhere on the board
LED17: RN5.7 (2); also elsewhere on the board
LED18: RN5.6 (2); also elsewhere on the board
LED19: RN5.5 (2); also elsewhere on the board
LED20: RN6.8 (2); also elsewhere on the board
LED21: RN6.7 (2); also elsewhere on the board
LED22: RN6.6 (2); also elsewhere on the board
LED23: RN6.5 (2); also elsewhere on the board
LED24: RN7.8 (2); also elsewhere on the board
LED25: RN7.7 (2); also elsewhere on the board
LED26: RN7.6 (2); also elsewhere on the board
LED27: RN7.5 (2); also elsewhere on the board
LED28: RN8.8 (2); also elsewhere on the board
LED29: RN8.7 (2); also elsewhere on the board
LED30: RN8.6 (2); also elsewhere on the board
LED31: RN8.5 (2); also elsewhere on the board
LED32: RN9.8 (2); also elsewhere on the board
LED33: RN9.7 (2); also elsewhere on the board
LED34: RN9.6 (2); also elsewhere on the board
LED35: RN9.5 (2); also elsewhere on the board
LED36: RN10.8 (2); also elsewhere on the board
LED37: RN10.7 (2); also elsewhere on the board
LED38: RN10.6 (2); also elsewhere on the board
LED39: RN10.5 (2); also elsewhere on the board
LED40: RN11.8 (2); also elsewhere on the board
LED41: RN11.7 (2); also elsewhere on the board
LED42: RN11.6 (2); also elsewhere on the board
LED43: RN11.5 (2); also elsewhere on the board
LED44: RN12.8 (2); also elsewhere on the board
LED45: RN12.7 (2); also elsewhere on the board
LED46: RN12.6 (2); also elsewhere on the board
LED47: RN12.5 (2); also elsewhere on the board
LED48: RN13.8 (2); also elsewhere on the board
LED49: RN13.7 (2); also elsewhere on the board
LED50: RN13.6 (2); also elsewhere on the board
LED51: RN13.5 (2); also elsewhere on the board
LED52: RN14.8 (2); also elsewhere on the board
LED53: RN14.7 (2); also elsewhere on the board
LED54: RN14.6 (2); also elsewhere on the board
LED55: RN14.5 (2); also elsewhere on the board
LED56: RN15.8 (2); also elsewhere on the board
LED57: RN15.7 (2); also elsewhere on the board
LED58: RN15.6 (2); also elsewhere on the board
LED59: RN15.5 (2); also elsewhere on the board
LED60: RN16.8 (2); also elsewhere on the board
LED61: RN16.7 (2); also elsewhere on the board
LED62: RN16.6 (2); also elsewhere on the board
LED63: RN16.5 (2); also elsewhere on the board
LED64: RN17.8 (2); also elsewhere on the board
LED65: RN17.7 (2); also elsewhere on the board
LED66: RN17.6 (2); also elsewhere on the board
LED67: RN17.5 (2); also elsewhere on the board
LED68: RN18.8 (2); also elsewhere on the board
LED69: RN18.7 (2); also elsewhere on the board
LED70: RN18.6 (2); also elsewhere on the board
LED71: RN18.5 (2); also elsewhere on the board
LED72: RN19.8 (2); also elsewhere on the board
LED73: RN19.7 (2); also elsewhere on the board
LED74: RN19.6 (2); also elsewhere on the board
LED75: RN19.5 (2); also elsewhere on the board
LED76: RN20.8 (2); also elsewhere on the board
LED77: RN20.7 (2); also elsewhere on the board
LED78: RN20.6 (2); also elsewhere on the board
LED79: RN20.5 (2); also elsewhere on the board
unnamed: D3.P$1 (A9), RN1.1
unnamed: D3.P$2 (A8), RN1.2 (1)
unnamed: D3.P$3 (A7), RN1.3 (1)
unnamed: D3.P$4 (A6), RN1.4 (1)
unnamed: D3.P$5 (A5), RN2.1
unnamed: D3.P$6 (A4), RN2.2 (1)
unnamed: D3.P$7 (A3), RN2.3 (1)
unnamed: D3.P$8 (A2), RN2.4 (1)
unnamed: D3.P$9 (A1), RN3.1
unnamed: D3.P$10 (A), RN3.2 (1)
unnamed: D4.P$1 (A9), RN3.3 (1)
unnamed: D4.P$2 (A8), RN3.4 (1)
unnamed: D4.P$3 (A7), RN4.1
unnamed: D4.P$4 (A6), RN4.2 (1)
unnamed: D4.P$5 (A5), RN4.3 (1)
unnamed: D4.P$6 (A4), RN4.4 (1)
unnamed: D4.P$7 (A3), RN5.1
unnamed: D4.P$8 (A2), RN5.2 (1)
unnamed: D4.P$9 (A1), RN5.3 (1)
unnamed: D4.P$10 (A), RN5.4 (1)
unnamed: D5.P$1 (A9), RN6.1
unnamed: D5.P$2 (A8), RN6.2 (1)
unnamed: D5.P$3 (A7), RN6.3 (1)
unnamed: D5.P$4 (A6), RN6.4 (1)
unnamed: D5.P$5 (A5), RN7.1
unnamed: D5.P$6 (A4), RN7.2 (1)
unnamed: D5.P$7 (A3), RN7.3 (1)
unnamed: D5.P$8 (A2), RN7.4 (1)
unnamed: D5.P$9 (A1), RN8.1
unnamed: D5.P$10 (A), RN8.2 (1)
unnamed: D6.P$1 (A9), RN8.3 (1)
unnamed: D6.P$2 (A8), RN8.4 (1)
unnamed: D6.P$3 (A7), RN9.1
unnamed: D6.P$4 (A6), RN9.2 (1)
unnamed: D6.P$5 (A5), RN9.3 (1)
unnamed: D6.P$6 (A4), RN9.4 (1)
unnamed: D6.P$7 (A3), RN10.1
unnamed: D6.P$8 (A2), RN10.2 (1)
unnamed: D6.P$9 (A1), RN10.3 (1)
unnamed: D6.P$10 (A), RN10.4 (1)
unnamed: D7.P$1 (A9), RN11.1
unnamed: D7.P$2 (A8), RN11.2 (1)
unnamed: D7.P$3 (A7), RN11.3 (1)
unnamed: D7.P$4 (A6), RN11.4 (1)
unnamed: D7.P$5 (A5), RN12.1
unnamed: D7.P$6 (A4), RN12.2 (1)
unnamed: D7.P$7 (A3), RN12.3 (1)
unnamed: D7.P$8 (A2), RN12.4 (1)
unnamed: D7.P$9 (A1), RN13.1
unnamed: D7.P$10 (A), RN13.2 (1)
unnamed: D8.P$1 (A9), RN13.3 (1)
unnamed: D8.P$2 (A8), RN13.4 (1)
unnamed: D8.P$3 (A7), RN14.1
unnamed: D8.P$4 (A6), RN14.2 (1)
unnamed: D8.P$5 (A5), RN14.3 (1)
unnamed: D8.P$6 (A4), RN14.4 (1)
unnamed: D8.P$7 (A3), RN15.1
unnamed: D8.P$8 (A2), RN15.2 (1)
unnamed: D8.P$9 (A1), RN15.3 (1)
unnamed: D8.P$10 (A), RN15.4 (1)
unnamed: D9.P$1 (A9), RN16.1
unnamed: D9.P$2 (A8), RN16.2 (1)
unnamed: D9.P$3 (A7), RN16.3 (1)
unnamed: D9.P$4 (A6), RN16.4 (1)
unnamed: D9.P$5 (A5), RN17.1
unnamed: D9.P$6 (A4), RN17.2 (1)
unnamed: D9.P$7 (A3), RN17.3 (1)
unnamed: D9.P$8 (A2), RN17.4 (1)
unnamed: D9.P$9 (A1), RN18.1
unnamed: D9.P$10 (A), RN18.2 (1)
unnamed: D10.P$1 (A9), RN18.3 (1)
unnamed: D10.P$2 (A8), RN18.4 (1)
unnamed: D10.P$3 (A7), RN19.1
unnamed: D10.P$4 (A6), RN19.2 (1)
unnamed: D10.P$5 (A5), RN19.3 (1)
unnamed: D10.P$6 (A4), RN19.4 (1)
unnamed: D10.P$7 (A3), RN20.1
unnamed: D10.P$8 (A2), RN20.2 (1)
unnamed: D10.P$9 (A1), RN20.3 (1)
unnamed: D10.P$10 (A), RN20.4 (1)

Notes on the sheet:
Resistor Arrays names :
Resistor Arrays values :

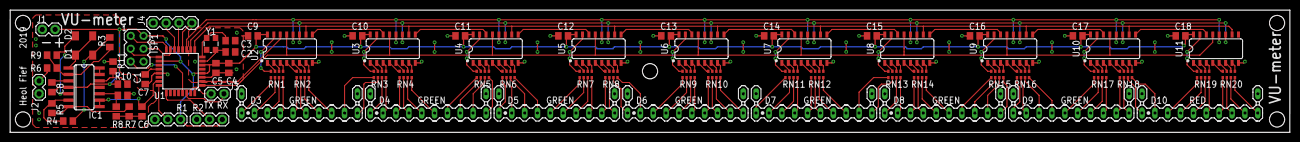
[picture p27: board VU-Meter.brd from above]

Board: 2 copper layers, 252.7 x 24.1 mm, 77 parts (0 on the bottom side), 202 nets.

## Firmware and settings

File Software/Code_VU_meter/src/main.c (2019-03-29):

/**
 * \file main.c
 * \brief main program
 * \author Heol Fief
 *
 * Main program for the VU-meter. Initialize everything needed for program to work, and loop forever.
 *
 */

#ifndef F_CPU
#define F_CPU 16000000UL // 16 MHz clock speed
#endif

#include <avr/io.h>
#include <util/delay.h>
#include <avr/interrupt.h>
#include "Peripherals.h"
#include "usart.h"
#include "hc595.h"
#include "Config.h"
#include "wdt.h"
#include "test.h"
#include "dsp.h"


audio_object audio_sample;

int data_smpl_counter = 0;
float audio_avg;
float gain = 1;
uint16_t threshold = 30;
uint8_t sample_ready = 0;
uint8_t adc_channel;
uint16_t adc_raw=0;

/**
 * \fn int main(void)
 * \brief Main program.
 *
 * \return Nothing. Loops forever.
 */
int main(void)
{
	//wdt_init();
	tmr0_init();
	adc_init();
	io_init();
	
	#ifdef UART_DEBUG
	uart_set_FrameFormat(USART_8BIT_DATA|USART_1STOP_BIT|USART_NO_PARITY|USART_ASYNC_MODE);
	uart_init(BAUD_CALC(115200));
	#endif
	
	sei();		// Enable interrupts
	
	
	audio_sample.vu_value = 56;
	audio_sample.peak_value = 72;
	
	while(1)
    {
		//watchdogReset();										// Feed the watchdog
		if(sample_ready)
		{
			sample_ready = 0;									// reset flag
			dsp_VU_peak_compute(&audio_sample);					// Compute acquired data
			
			#ifdef UART_DEBUG
			test_audio(&audio_sample);							// Send data via serial (debug only)
			#endif
			
			HC595Write(audio_sample.vu_value, audio_sample.peak_value);// Light up LEDs
			
			if(adc_channel & 1) ADMUX = GAIN_ADC_CHANNEL & 0b111;// ...
			else ADMUX = THRESHOLD_ADC_CHANNEL & 0b111;			// ... Alternate between ADC channel selection
			ADMUX &= ~(1<<REFS1);								// ...
			ADMUX |= (1<<REFS0);								// ... VCC used as Voltage Reference
			++adc_channel;										// Increase counter
		}
		_delay_ms(1);
    }
}


/**
 * \fn ISR(ADC_vect)
 * \brief Interrupt Service Routine on ADC conversion complete. NOT A FUNCTION, automatically called by hardware.
 * 
 * Performs analog data acquisition and filtering calculation.
 */
ISR(ADC_vect)											// Interrupt on ADC conversion complete
{
	adc_raw = ADC;										// Get ADC RAW data

	TIFR0=(1<<OCF0A);									// Disable tmr0 comp match a interrupt
	
	if ((ADMUX & 0b111) == AUDIO_ADC_CHANNEL)			// If ADC read audio signal
	{		
		adc_raw = (float)adc_raw * gain;				// Multiply signal by gain
		if(adc_raw>1023)adc_raw=1023;					// Stay on 10bits representation
		
		if (adc_raw < threshold) adc_raw = threshold;	// Ignore signal under threshold
		
		audio_avg += adc_raw;							// Average data (1/2)
		
		++data_smpl_counter;							// Increment number of data sampled
		
		if(data_smpl_counter == AVERAGEWIDTH)			// Down-sampling from 10kHz to 100Hz (divide by 100)
		{
			audio_avg /= AVERAGEWIDTH;					// Average data (2/2)
			audio_avg = (audio_avg-threshold)*(1023)/(1023-threshold); // Map audio_avg between 1023 and threshold
			
			audio_sample.adc_avg = (uint16_t)audio_avg; // Save average value
			sample_ready = 1;							// Enable sample ready flag
			data_smpl_counter = 0;						// Reset samples counter 
		}
		return;
	}
	
	if ((ADMUX & 0b111) == GAIN_ADC_CHANNEL)			// If ADC reads gain level
	{
		gain = (float)adc_raw * (GAIN_MAX - GAIN_MIN) / (1023.0) + GAIN_MIN; // Map gain between GAIN_MIN and GAIN_MAX
		ADMUX = AUDIO_ADC_CHANNEL & 0b111;				// Select back ADC channel
		ADMUX |= (1<<REFS1) | (1<<REFS0);				// Internal 1.1V used as Voltage Reference
		return;
	}
	
	if ((ADMUX & 0b111) == THRESHOLD_ADC_CHANNEL)		// If ADC reads threshold level
	{
		//threshold = adc_raw >> 5;
		ADMUX = AUDIO_ADC_CHANNEL & 0b111;				// Select back ADC channel
		ADMUX |= (1<<REFS1) | (1<<REFS0);				// Internal 1.1V used as Voltage Reference
		return;
	}
}

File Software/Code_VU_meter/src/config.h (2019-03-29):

/**
 * \file config.h
 * \brief User-configuration file.
 * \author Heol Fief
 *
 * User configuration file. Change it to adapt code to your hardware.
 *
 */ 

// FUSES : avrdude command : -U lfuse:w:0xf7:m -U hfuse:w:0xde:m -U efuse:w:0xfd:m 


#ifndef CONFIG_H_
#define CONFIG_H_

//#define UART_DEBUG						// Uncomment this line if you want serial port debug 

/* SOFTWARE CONFIG */
#define AVERAGEWIDTH			100			// Number of samples for the digital filter (don't change, dependent on sampling frequency)
#define PEAK_HOLD_TIME			300			// Hold time for the peak before falling
#define PEAK_FALL_RATE			0.2			// Speed for the peak to fall

#define GAIN_MIN				0.8			// Minimal input signal gain
#define GAIN_MAX				10.0		// Maximal input signal gain

/* HARDWARE CONFIG */
#define NUMBER_OF_LED			80			// Number of LED for the VU meter display

#define AUDIO_ADC_CHANNEL		0			// ADC channel to read audio signal from
#define GAIN_ADC_CHANNEL		1			// ADC channel to read gain from
#define THRESHOLD_ADC_CHANNEL	2			// ADC channel to read threshold from

#define HC595_PORT				PORTD		// IO port where HC595 is connected
#define HC595_DDR				DDRD		// DATA DIRECTION REGISTER of the port chosen above

#define HC595_SER				PD4		    // Data pin (DS) pin location
#define HC595_SCK				PD6			// Shift Clock (SH_CP) pin location
#define HC595_RCK				PD7			// Register Clock (SH_CP) pin location
#define HC595_SCL				PD5			// Serial clear (active LOW) pin location
#define HC595_OE				PD3			// Output Enable (active LOW) pin location

#endif /* CONFIG_H_ */

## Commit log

2019-03-29 Add hardware files
    [VU-Meter.brd, VU-Meter.sch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]
2019-06-27 Add leds

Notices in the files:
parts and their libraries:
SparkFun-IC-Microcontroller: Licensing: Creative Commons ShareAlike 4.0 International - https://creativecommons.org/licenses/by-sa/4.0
